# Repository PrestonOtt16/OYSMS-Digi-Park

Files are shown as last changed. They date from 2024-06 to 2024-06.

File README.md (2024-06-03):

# OYSMS-Digi-Park
Preston Ott 6/2/2024
This is a Univerity of Texas at San Antonio Senior Design Project completed on the date of 4/23/2024
Group members: Preston Ott, Josh Swanner, Joshua Moya, Younes Younes, Luis Santillian

The projects goal was too make an app that displays a parking lot map showing which parking spaces are occupied/unoccupied for navigation purposes. 

The projects detailed goal was to create a wireless sensor system that will scan a parking lot.
The scan will be fed to a machine learning model that detects if parking spaces are occupied or not.
The machine learning model will send the parking space data to a server hosting a mobile app.
The mobile app will use the data to create and display a map of the parking lot to the mobile app user.
The mobile app user will use the map too find the nearest unoccupied parking space.

Link to demonstration of final project:
https://www.youtube.com/watch?v=veE5finqBho

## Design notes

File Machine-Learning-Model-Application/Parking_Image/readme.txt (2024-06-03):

This directory holds the image the rpi4 camera captures

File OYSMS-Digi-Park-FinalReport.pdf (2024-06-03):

Final Report – 5/2/2022

EE/CpE 4813 – ECE Capstone Design II

Spring 2023

Instructors: | Johnathan Votion Ph.D, Professor August Allo.
Team name: | OYSMS Digipark
Team members: | Preston Ott, Younes Younes, Joshua Swanner, Joshua Moya, Luis
Santillan
Description: | The Parking Space Indicator is a project that will map a parking lot,
develop a scanner to scan parking spaces and develop an app to display occupied/unoccupied parking spots in the parking lot.

Executive Summary
The OYSMS Digipark team's prototype scanner and app were developed with the goal of providing real-time occupancy status of a parking lot to users. The project was designed to alleviate the stress and frustration of finding a parking spot by allowing users to check the availability of parking spots before they arrive at the parking lot. The team incorporated a machine learning model to accurately detect the occupancy of parking spots, which was transmitted to a receiver and stored in a SQL database for easy retrieval by the app. The team also made adjustments to the hardware components, such as the camera and microcontroller, to ensure the reliability and ease of use of the final product.

Overall, the project was a success, with the final prototype demonstrating the team's ability to create an innovative solution to a common problem. The team's ability to adapt and innovate when faced with challenges was crucial in achieving the project goals.

Here are two images of the final the prototype:

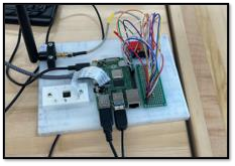
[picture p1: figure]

Image 1. Final Prototype

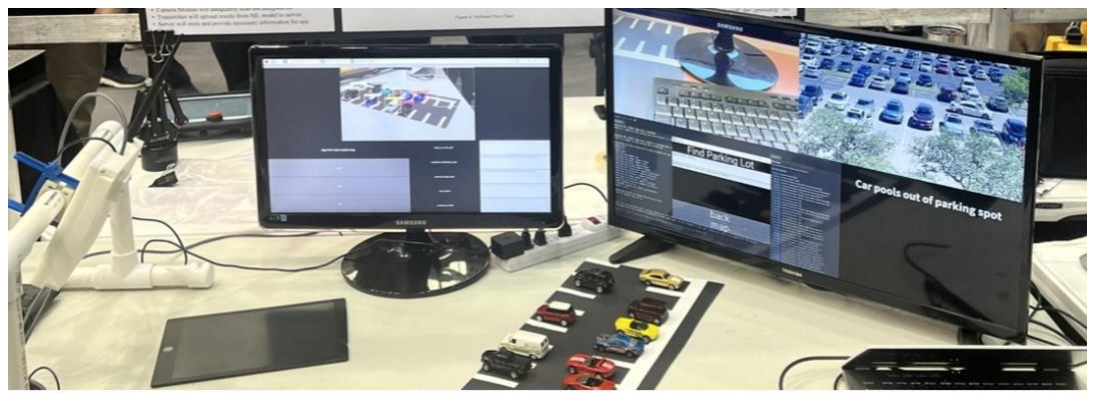
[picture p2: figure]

Image 2. Final Prototype working

Additionally, here is a video demonstration of the final prototype:

Parking Project Demonstration-2023-OYSMS-Digi-Park (https://youtu.be/veE5finqBho)

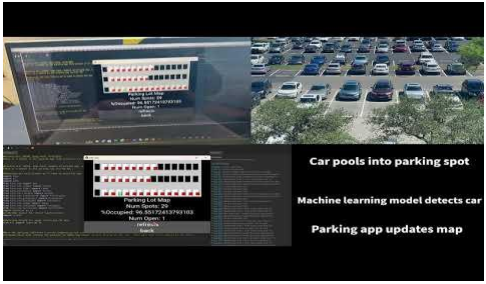
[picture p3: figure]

Video 1: Video of Final Prototype Working

### 1.0 Introduction

We are OYSMS Digipark. This project aims to set up a scanner in a parking lot which can also update an app that can be viewed on an electronic device. The project will first take a picture through the camera of the desired parking lot that the user is looking for. The camera will then send that photo to the machine learning model to process the Afterwards, a spot array will be created that contains 1’s and 0’s depicting the occupancy of each parking spot. The transmitter will then send the spot array to the receiver. Once received the receiver will update a SQL database that will be used to store the spot array. The user will type in the desired address in the app which will request a spot array through the server. Finally, the server sends the spot array to the user and the users app will display the parking spots that are occupied and unoccupied with vehicles.

### 1.1 Project Schedule

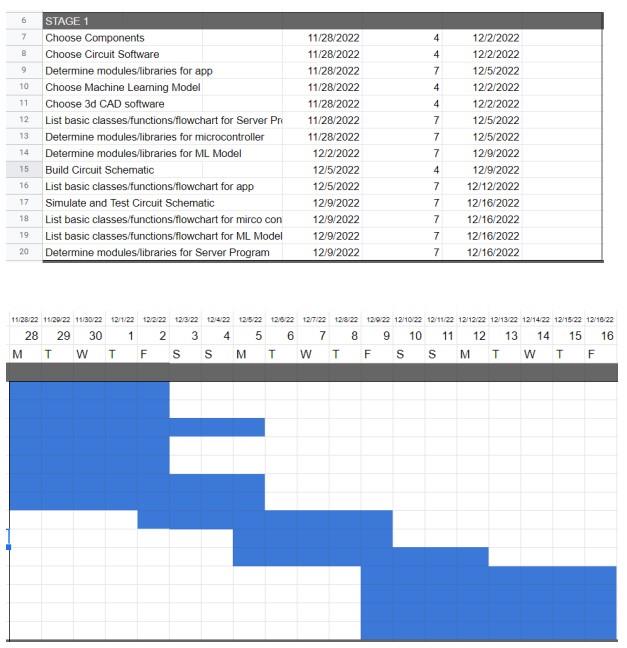
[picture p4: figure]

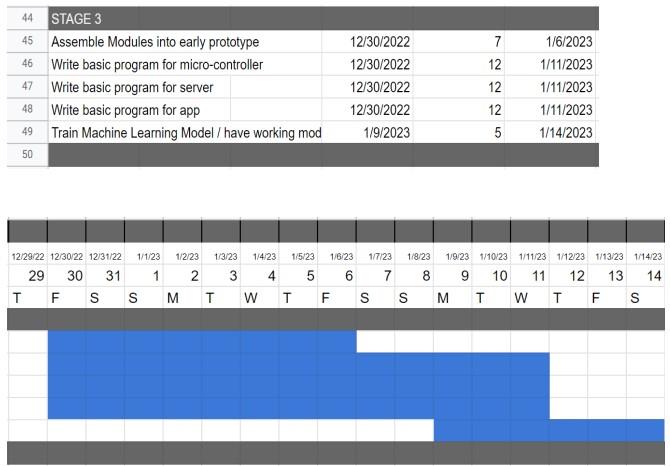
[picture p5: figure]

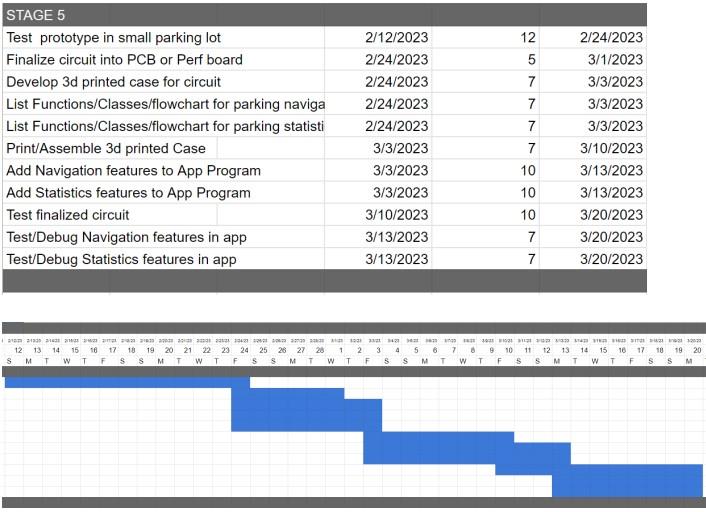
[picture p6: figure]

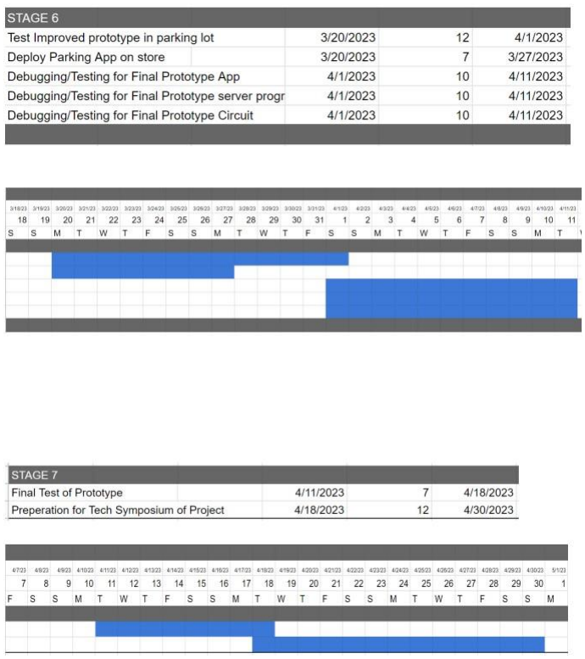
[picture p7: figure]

### 2.0 Need Being Addressed

A problem that has been an issue for some time now is the parking around campus. Finding a parking spot on campus can be tough because there are so many people trying to go to class, and with a limited number of spots it is hard to know if other parking lots have open parking spots. This will help many people find parking on campus with little to no struggles. All businesses and buildings that have parking lots will benefit from this solution because customers avoid shops due to inadequate parking space. All people who use a motor vehicle will benefit from this solution through fuel and time savings.

### 3.0 Literature and Patent Search Results

Researching Parkam’s AI-based deep machine learning software provided the team with a vision of how our product should function. Their patent for a training system for automatically detecting parking space vacancy providing inspiration towards training our own machine learning program. The ability to identify parking spots and their states accurately being the main inspiration. With Cleverciti’s parking sensor providing the basis for the physical aspect of the OYSMS scanner. Although ours is made of a more cost-effective material, uses a single camera and customizable clamps for adjustable attachment to various surfaces.

### 4.0 Marketing Analysis and Market Strategy

The market potential of this product is vast and promising. In a full parking lot,
customers will get frustrated and start to leave the premises, meaning the company will start to lose money. Companies could use this app to help reduce the amount of potential customers from going to a different store. With this product implemented into businesses parking lots, customers would want to come more often because of how convenient it is for them to find a parking space. This would potentially make the business grow and the product grow as well because then customers would start to look for businesses that are associated with the app to start shopping at.

### 5.0 Engineering Design Constraints

The main constraint of the application are the guidelines placed on by the app stores and the capabilities of the programming language being used to develop the app. For the device there are rules and standards given by the FCC when transmitting radio frequencies. Another constraint would be communicating the devices' information to the server running our application.

### 6.0 Product Requirements/Specifications

This section of the document lists specific requirements and specifications for OYSMS DigiPark. Requirements and specifications are divided into the following sections:

1. User requirements and specifications. These are requirements and specifications written from the point of view of end users, usually expressed in narrative form.
2. System requirements and specifications. These are detailed requirements and specifications describing the functions the system must be capable of doing.
3. Interface specifications. These are requirements and specifications about the user interface, which may be expressed as a list, as a narrative, or as images of screen mock-ups.

### 6.1 User Requirements and Specifications

6.1.1 User interface

The user interface will be available from a mobile app that the user will be able to use on their cellular device. They will be able to look at the parking spaces available and the parking lots that are available and the ones that aren’t available.

6.1.2 Ergonomics

This product will be in the air above the reach of anyone, so that it will be able to scan the designated area. This will make sure it is not in anyone’s way.

6.1.3 Training or skills required

Technical understanding and experience of operating a smart device is required for the app. To be able to use the app you just must know how to use your phone. Being able to navigate through the app without any trouble. You also need to be able to drive and/or have navigation skills to get to the designated spot.

### 6.2 System Requirements and Specifications

6.2.1 Physical Characteristics

- Raspberry pi 4
- Weight: | 46 g
- Dimensions: | 85.6mm x 56.5mm
- Transmitter
- Weight: | 15.4 g
- Dimensions: | 0.63x0.63x0.07 in
- Camera
- Weight: | 34 x 24 mm
- Dimensions: | 20 g

6.2.2 Material Requirements

- 3-D Printed case

6.2.3 Electrical Requirements

- Raspberry pi 4:
- Power: 5V DC, 2.5A
- Operating System: Python
- Operating Temperature: 0-50 degrees C

6.2.4 Abilities

- Take an image and processing that image

6.2.5 Limitations

- Not enough range to cover every parking lot simultaneously
- Wi-Fi signal not strong enough

6.2.6 Equipment or materials required to use the product

- Smart Phone
- Mobile App installed

6.2.7 Equipment interface requirements

- SD memory storage reading capabilities

6.2.8 Handling and storage requirements

- Needs to be up high in the air

6.2.9 Cleaning and Sterilization

- Cleaning the camera is going to be essential for us to get a clear picture of the parking lot

6.2.10 Product maintenance and serviceability

- Cleaning the camera to get a clearer picture
- Fixing the bugs of the app as we go along
- Wi-Fi needs to be available

6.2.11 Operating parameters

- OV5647
- Power Supply: 3.3V - 5V
- Pixel Size: 1.4µm x 1.4µm
- Temperature: -10°C～+55°C
- Raspberry pi 4
- Power Supply: 5V DC, 2.5A
- Temperature: 0-50 degrees C
- RFM95
- Power Supply: 3.3V
- Temperature: -55°C～+115°C

6.2.12 Repeatability and reproducibility

- The project is going to be able to refresh and be able to repeat each process every 15 seconds. If the camera is going to be clean, then there should be no problems.

6.2.13 Reliability

- Depending on the weather conditions and other conditions, this product will be reliable on any day. Up to the user to refresh the app to see availability.

6.2.14 Mechanical safety features

- 3-D printed case

6.2.15 Electrical safety features

- Raspberry Pi 4
- Wires
- Transmitter
- Camera
- PCB

### 6.3 Interface Requirements and Specifications

Access and translation between the digital camera and transmitter should be monitored by our microcontroller. For the sake of consistent image upload to a database server which will translate said information into a readable form for our users. From this, our users will interact with the given parking information via an application that will take user input and guide them to their desired location. The device will be detached from the elevated location for maintenance if physical repairs are necessary and updates to the server can be done at a separate location.

### 7.0 Engineering Codes and Standards

Below are the IEEE standards for transmitting data over radio frequencies and other wireless forms of communication. As our devices require wireless connectivity to communicate with the server and application, these standards and regulations are required:

IEEE Standard for Radio-Frequency Energy and Current-Flow Symbols: Symbols to inform people about the presence of potentially hazardous levels of radiofrequency energy or the presence of contact current hazards in the frequency range of 3 kHz to 300 GHz are specified in this standard. Guidance is given about how these symbols should be used on warning signs and labels.

IEEE Recommended Practice for Radio Frequency Safety Programs, 3 kHz to 300 GHz: Elements of a radio frequency (RF) exposure safety program that provide reasonable and adequate guidance for preventing exposures in excess of recognized limits to electromagnetic fields from RF sources that operate in the frequency range of 3 kHz to 300 GHz are described in IEEE Std C95.7™-2014. The means for accomplishing this are classifying exposure locations into one of four categories based on the potential hazard, as defined by exposure limits, and specifying appropriate controls for each category. Such controls include engineering and administrative controls as well as the use of personal protective equipment, placement of appropriate RF safety signage, designation of restricted access areas, the use of personal RF monitors, and RF safety awareness training. These recommendations are not intended to apply to the purposeful exposure of patients by or under the direction of medical practitioners but can be used in the development of safety programs for medical staff and other persons working with or incidentally exposed to RF fields, and for those wearing implanted or external medical electronic devices. Although designed to complement IEEE Std C95.1™, this recommended practice may also be used for the development of programs to ensure conformance with other guidelines, standards, or regulations for controlling human exposure to electromagnetic energy.

IEEE Guide for EMF Exposure Assessment of Internet of Things (IoT) Technologies and Devices: In the wireless communication field, 5G and Internet of Things (IoT) solutions are the main emerging technologies and future wireless communication will rely on them. A methodology for classifying IoT devices based on radio frequency (RF) exposure characteristics is provided. Classification is based on frequency, bandwidth, radiated power, and typical installation configuration. Links between device class and available measurement/computational standards are provided.

### 8.0 Design Concepts

When discussing how the go about this project our team settled on three concepts to compare and discuss. Below is a Pugh Matrix with weighting of importance displayed within the second column alongside the determining criteria. From which the scanner module design was selected with a total score of 785.

Criteria | Weight | Drone | Sensor | Scanner Module
Cost: | 20 | 5 | 4 | 8
Efficiency: | 30 | 6 | 8 | 8
Information Quality: | 10 | 8 | 10 | 8
Transmit speed: | 10 | 8 | 8 | 8
Temperature ratings: | 15 | 9 | 8 | 8
Scan Rate: | 15 | 6 | 8 | 7
Score = | 100 | 539 | 740 | 785

### 8.1 Drone Concept

A concept utilizing a drone to periodically survey an area and collect parking lot information. However, as power constraints are quite limiting, scan rates are not as frequent as desired and less efficiency in larger areas, this idea was inevitably the least favored amongst the three options.

### 8.2 Sensor Concept

The light sensor method would utilize a scanner device that would project a signal upon a sensor on the ground in a parking spot. The sensor would receive and reflect the signal back unless something such as a vehicle blocks the signal, which would notify the main device that the spot is occupied. While this method is effective for condensed areas, it’s not as effective in larger lots where several receiver nodes would be required. Also, the signal could be blocked by something not actually occupying the space such as a person blocking the sensor.

### 8.3 Scanner Module Concept

Using a scanner module and a machine learning algorithm, this device could observe a lot and detect changes within real time like the sensor concept. Trading some detection speed and a bit of information quality for more accuracy and cost efficiency in larger areas, the scanner module is the more desirable option by comparison. This device could even identify the difference between a vehicle and a person or tree branch that’s simply obstructing view with more advanced Artificial Intelligence.

### 9.0 High Level Block Diagram

The parking lot scanner block consists of a scanner, a control system, a transmitter, and a power supply. Firstly, the power supply subsystem will provide voltage to the other subsystems in the parking lot scanner. Between 3.3 and 5 volts of power will be input to the power supply, note that many circuits operate. The first major subsystem is the scanner. The scanner will be given an input of a physical car and/or parking spot. The scanner may be given an individual car/parking spot, or it may be given several cars/parking spots dependent on the type of scanner being used (ultrasonic, photodiode, camera, etc.). The control system will act as a brain for the whole parking lot scanner. The main purpose of the control system will be to take the data from the scanner and interpret it. It may then simplify the data and output the data to the transmitter along with instructions. The instructions sent to the transmitter may consist of how often to transmit, what data to transmit, what frequency to transmit at, when to turn off, etc. The main input of the transmitter will be the data of the scanner (from the control system) and will output the same data over the air. The main purpose of the transmitter is to communicate and update the server with the important information sent from the control system. The parking space app will be decomposed into 2 main parts: the client app and the server program. We’ll require a server for our project which can be any desktop computer. The server will take in 2 types of data, and these are client requests and scanner data. The second part of the parking space app will be the client app. This app will run on the client's device, which will most likely be a smartphone.

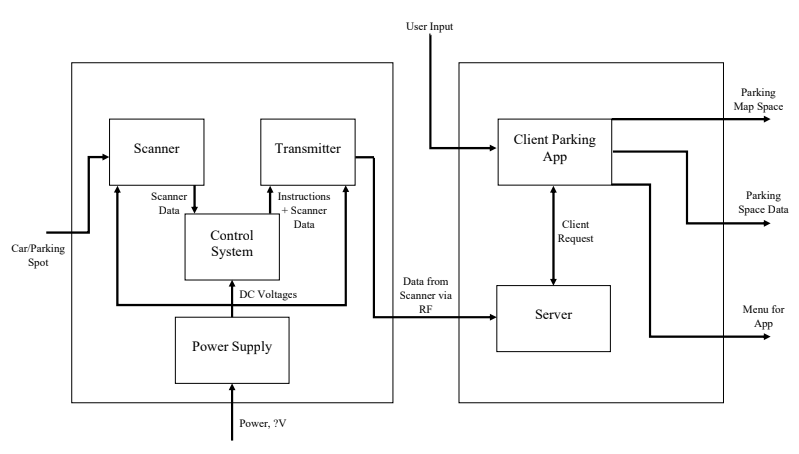
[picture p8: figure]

Figure 1: High Level Block Diagram

### 10.0 Major (Critical) Components

### 10.1 Camera Module

Criteria | Weight | OV5647 OmniVision
MT9P11
ONSemi

S5K4ECGX
Samsung
Cost: | 15 | 7 | 5 | 8
Output Formats: | 17 | 9 | 6 | 7
Image Quality: | 30 | 10 | 10 | 10
Interfacing Capabilities: | 19 | 9 | 7 | 7
Temperature ratings: | 10 | 8 | 9 | 8
Pixel Size: | 9 | 9 | 9 | 9
Score = | 100 | 989 | 781 | 833

Functional requirements for the digital camera Pugh matrix are cost, output formatting options, image quality, interfacing capabilities, temperature ratings, and size of pixels. The three digital cameras being analyzed are the OV5647, MT9P11, and the S5K4ECGX. The cost was weighed as the middle of the pack (15) because most camera modules have around the same price for similar specifications. Output formatting was rated similarly (17) because of how common the most important format options such as RAW, YCbCr422, and JPEG are across various models. Image quality is a crucial factor in determining our device (30) as the clearer the images provided, the smoother our program can operate.

Temperature and pixel size are the least consequential factors (10 and 9 respectively) because after observing various models most are more than capable of operating in extreme temperatures. With pixel size in a comparable situation as most camera modules have a 1.4um x 1.4um pixel ratio amongst the similar specifications. The OV5647, MT9P11, and the
S5K4ECGX got scores of 989, 781, and 833, respectively. Taking all the functional requirements into account the OV5647 surpasses the others in terms of quality.

### 10.2 Control system

Criteria | Weight | OV5647 OmniVision
MT9P11
ONSemi

S5K4ECGX
Samsung
Cost: | 10 | 8 | 9 | 10
I/O Ports: | 20 | 10 | 7 | 5
Programmability: | 20 | 10 | 6 | 8
Wi-fi Capabilities: | 10 | 9 | 7 | 10
Processor Speed: | 20 | 10 | 7 | 9
Storage: | 20 | 7 | 9 | 10
Score = | 100 | 910 | 740 | 840

Functional requirements for the microcontrollers Pugh matrix are cost, I/O ports, programmability, Wi-Fi capabilities, processor speed, and storage. The three microcontrollers that were being analyzed are the Arduino uno rev3, raspberry pi4, and the esp32. The cost weighed about 10 percent of the total with all of the microcontrollers ranging from a certain range, but with some slightly cheaper than the others. The I/O ports were rated at (20) because each microcontroller had either only 2 or 3 I/O ports while others had 5 or more. The Programmability was also weighed the same because some microcontrollers can only be programmed in one language while others can be programmed using more than one.

The Wi-Fi capabilities were weighed at (10) because it is a feature that is useful without having to use an ethernet cable. The Processor speed is the same weight of (20) and we need this to be able to make sure that the microcontroller can process what we send to it fast enough to keep up with what we are doing. Storage is also a big part of the weight with (20) having a lot of storage is good so that we can store the program code. With all these functional requirements, we can see that the Raspberry pi4 is the best option with a score of 910, the ESP32 is the second-best option with a score of 840 and then the Arduino uno rev3 is the last option with a score of 740.

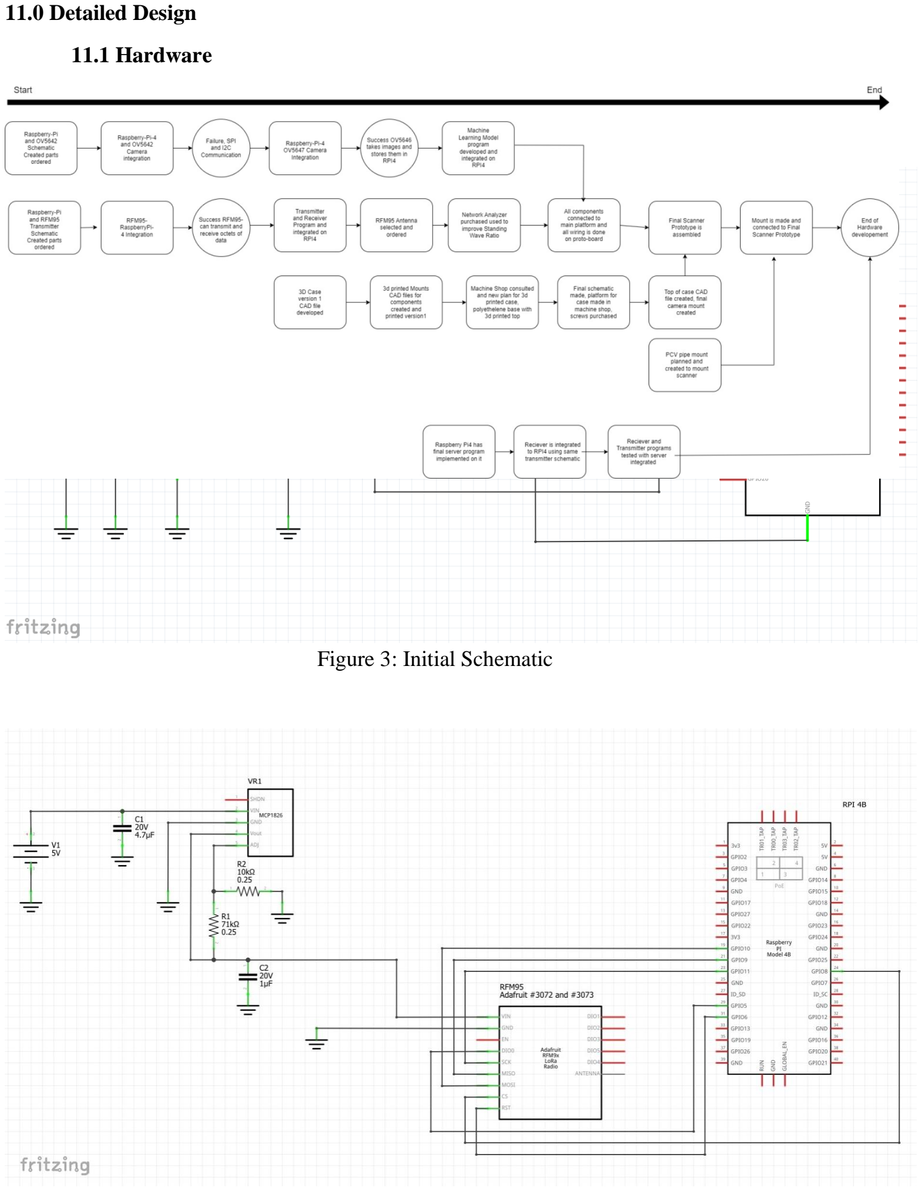
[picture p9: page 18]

### 11.0 Detailed Design

### 11.1 Hardware

Figure 2: Detailed Hardware Breakdown

Figure 3: Initial Schematic

Figure 4: 2

nd version of schematic without camera

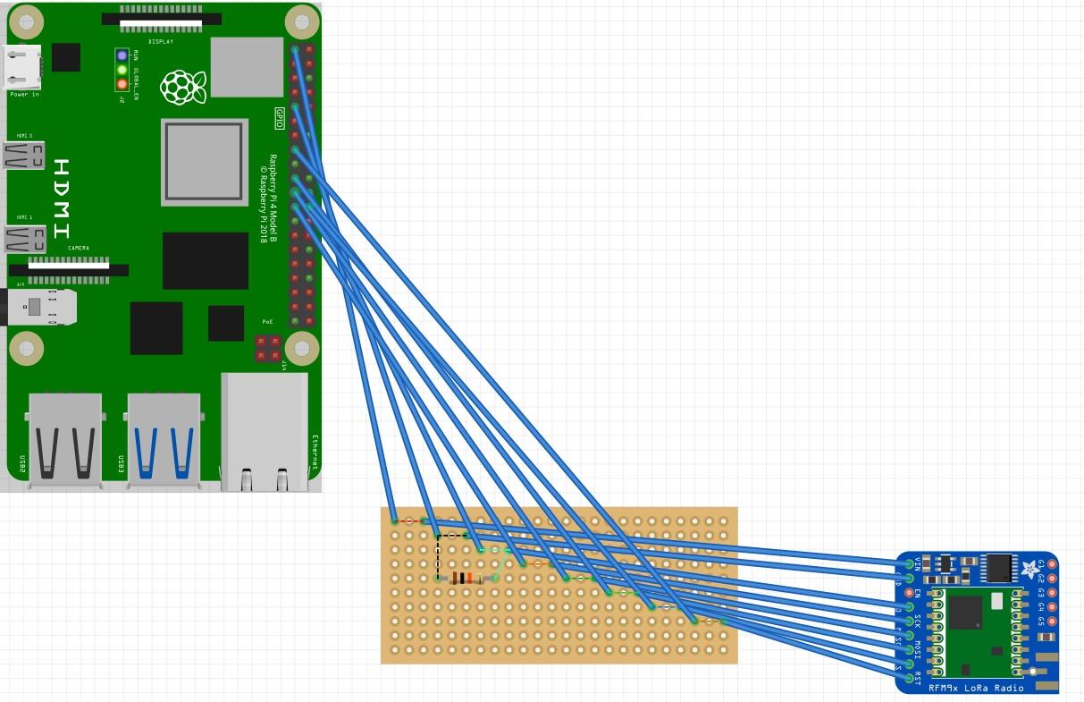
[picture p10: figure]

Figure 5: Final Schematic without camera

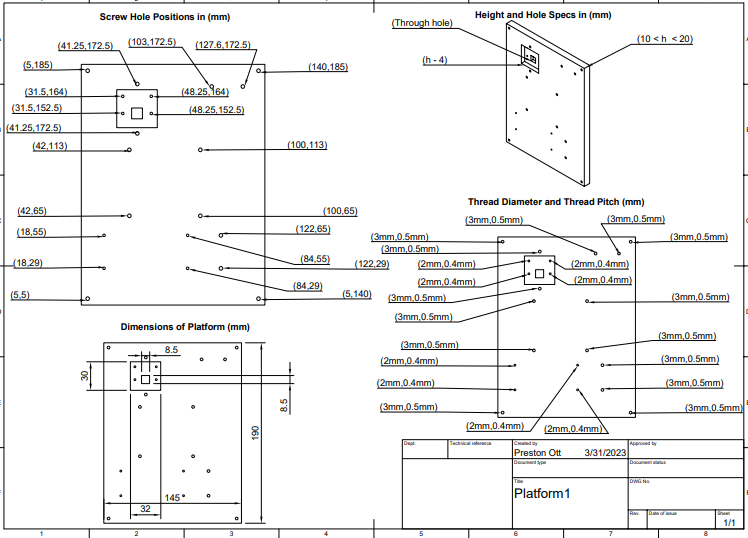
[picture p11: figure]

Figure 6: Plan for enclosure

The hardware ideas were split up between the majors. The computer engineers were to determine the best microcontroller to be used for the purpose of the project. While the electrical engineers were to focus on the transmitter/receiver, power supply, and the scanner.

### 11.1.1 Power

As seen in Figure 2, the raspberry pi was initially going to be powered with a voltage regulator. We then switched which regulator to be used after checking the power requirements for the raspberry pi as seen in figure 3. The resistors and capacitors were added to configure the regulator for the raspberry pi based of the data sheet. As time progressed, we saw more use with using the regular power supply made by a company and get rid of the regulator all together.

### 11.1.2 Scanner

The first iteration of the project used a different scanner (camera) than the final version. The scanner chosen ended up being a camera due to the capability of scanning multiple parking spots, which would otherwise be challenging with other sensors, such as ultrasonic. Early in the process the OV5647 was chosen to be the scanner, but due to difficulty interfacing with the raspberry pi, we decided to switch to the OV5642. Which was one of the first cameras produced to interface directly with the raspberry pi. This made the process of taking images much simpler, while still being an efficient camera for the project.

### 11.1.3 Transmitter/Receiver

The transceiver chosen held from beginning to end as seen in the schematics. The RFM95W was chosen to serve as the transmitter and receiver. One of the team members has had previous experience with the module at a past internship and has held this module with high regard. The transceiver chosen needed to be able to have a wide range to adapt to different parking lots, it also had to be able to send at least 80 parking spots worth of data. The RFM95, which has LoRa modulation scheme, has both long range while being able to send up to 255 bytes (or in this case parking spots) of data making it a good fit for Digipark.

### 11.1.4 Enclosure

Although not included in the hardware block diagram, the device needs to have an enclosure to secure and stabilize all of the parts. The process to design the case was to make a form factor efficient in size so that it could fit all the parts while being as small possible. The material to be used for printing was a resistant material to weather conditions while not conducting electricity. The material chosen that fit these requirements was ABS.

### 11.2 Software

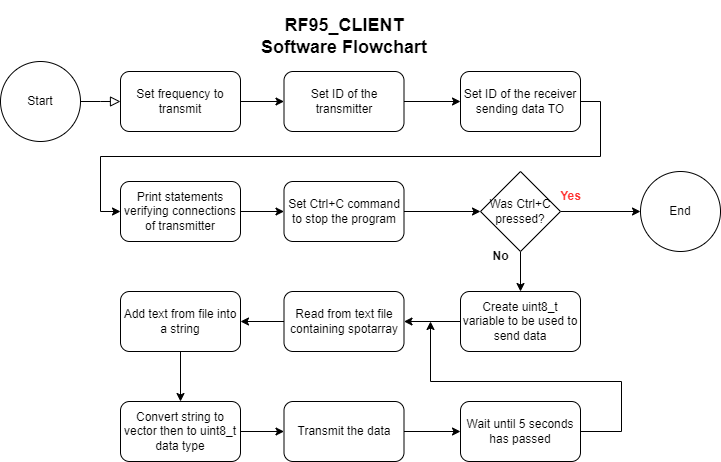
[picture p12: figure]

Figure 7: Transmitter Flow Chart

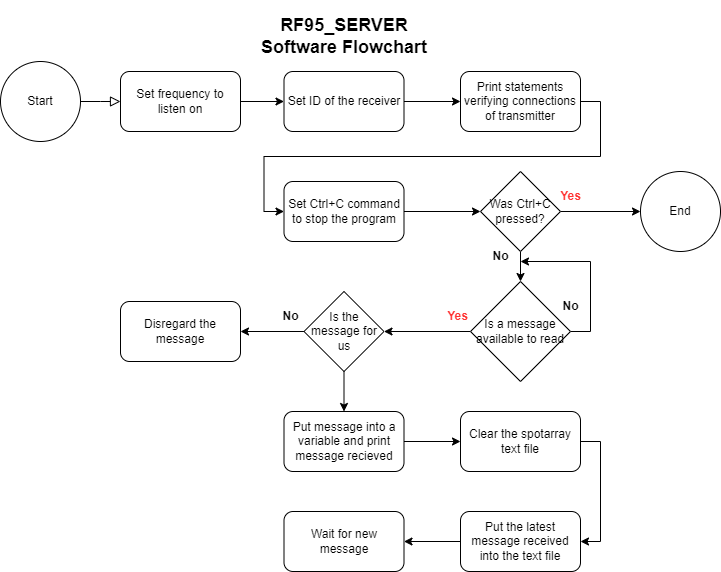
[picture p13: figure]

Figure 8: Sever Software Flowchart

The division of the software development is relatively straight forward. Having a member work on the code for whichever component they are most familiar with. While those with more advanced coding experience wrote code for the server and app.

### 11.2.1 Transmitter Software

The software starts by initializing the module itself, there is a required set of information for the first 8 bytes of every LoRa message, which contains information such as the name of the transmitter and where to send the data to. The program is setup to type Ctrl+C in the Linux terminal to end the program, but otherwise continue the program forever, since the device would always scan for parking spots. The Ctrl+C command would be used during less busy hours of a parking lot to save power. The way the module work, the data needs to be formatted into an array of the uint8_t data type, each array spot would contain 1 byte of information. The data being transmitted is the spot array which comes from a text file, which the transmitter program has to read. After reading the text file, a few data type conversions occur since there is no direct conversion from a text file to a uint8_t data type. After the conversions are complete, the transmitter finally sends the data to the receiver, and continually does this every 5 seconds.

### 11.2.2 Receiver Software

The receiver software starts by initializing the module, similar to the transmitter. The difference is that the ID will be used in a function that detects if the LoRa message was for the specific receiver. A similar loop of using Ctrl+C to end the program is used in the receiver as well, except the receiver always listens for a message. Once a message is received, the code checks if the message was for the receiver and discards the message if not. If the message is for the receiver, a second function is called to read the message and store the data in a variable. Afterwards, the program puts the message into a text file to be read and be manipulated by the server and database and continues to listen for a new message.

### 11.2.3 App Software

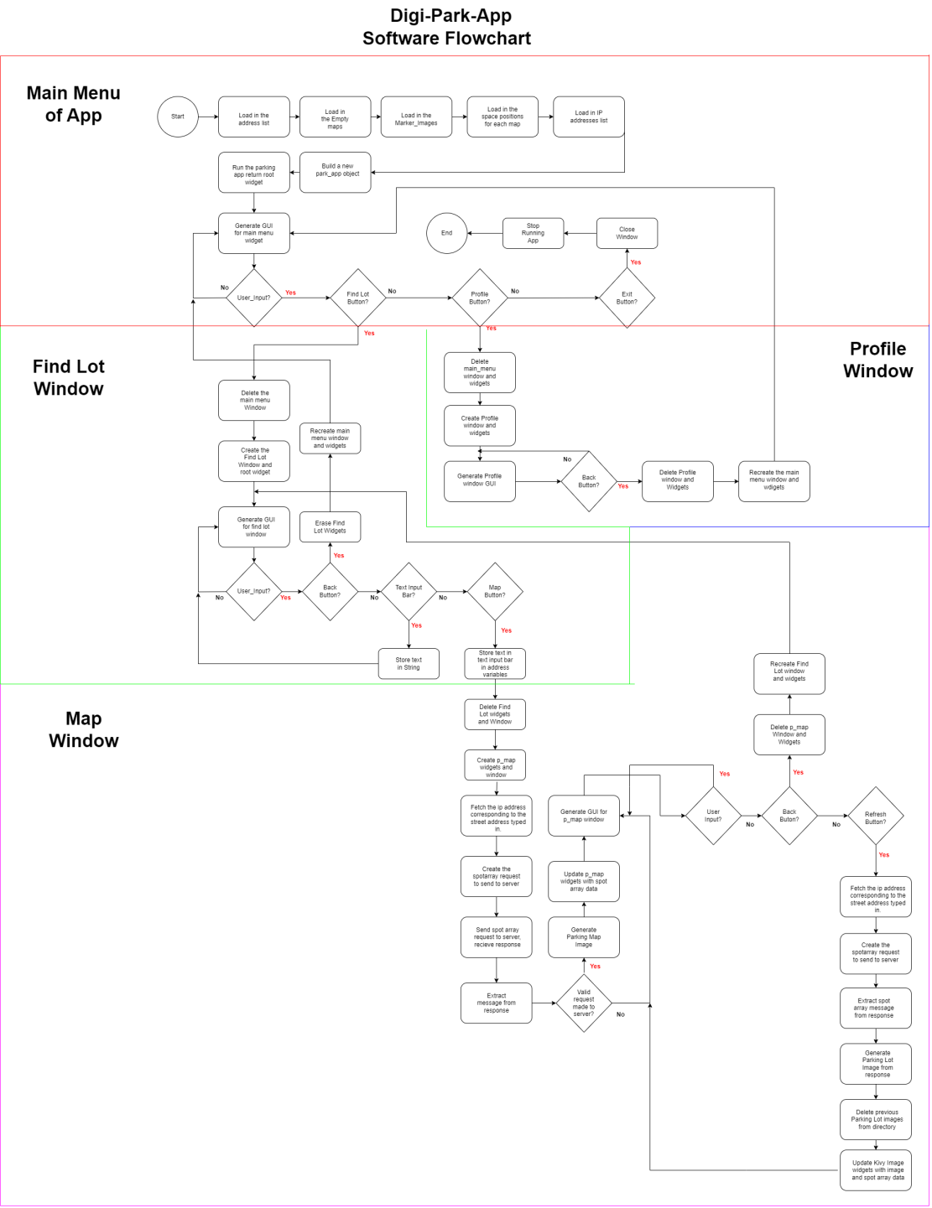
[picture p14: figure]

Figure 9: App Software Flowchart

The app software starts by loading in all the content Empty maps, position of parking spots, ip addresses, street addresses of parking lots, that it will need to properly function. Then an app object is created to generate the main menu window. From the main menu the user can navigate to profile window, find lot window. The profile window is not yet created and just contains some text and a back button. The Find lot window allows users to search through the street addresses and search for their own street address. Once a street address is typed into the text input the user can select the map button to receive the current parking lot map for the street address typed in. The app will send a request to the appropriate server for the (spot array) for that parking lot. The app will receive a (TCP) response from the server containing the spot array and close the (TCP) connection. The appropriate map from the Empty map folder will be selected and the parking lot map image will be drawn. Then statistics on the parking lot will be generated from the (spot array) received. The map window will then be drawn with the map image displayed to the user and the parking lot statistics. The user can then choose to refresh the page with the refresh button which will send another (spot array) request to the server to update the parking map image and statistics again. The user can also go back to the find lot window by clicking the back button. The user can navigate back to the exit button and click it, once clicked the window for the app will be closed and the app will stop running. The Kivy library documentation was used to develop the main Kivy app reference.

### 11.2.4 Machine Learning and Camera Software

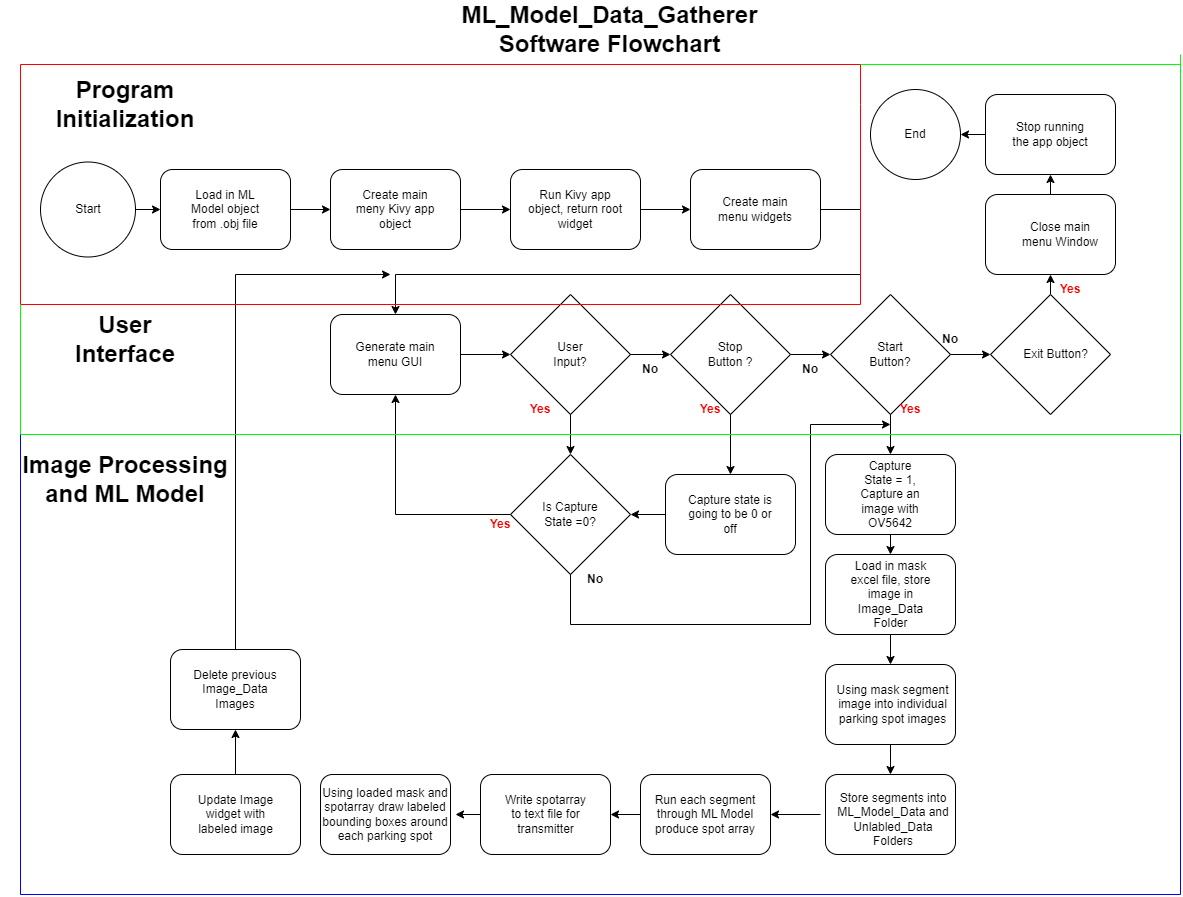
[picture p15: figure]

Figure 10: ML Software Flowchart

The Machine Learning Model and Camera and Software is within a program called ML_Model_Data_Gatherer.py. The program basically goes through the process of scanning and analyzing the parking lot. The program starts by loading a sci-kit-learn MLP Machine Learning Model object into the program. Then it creates a kivy app object and runs it. The app object creates the user interface menu for the user. The user can type in the path to the mask that defines the bounding boxes for the parking lot image. The user can press the stop button to stop scanning the parking lot, the user can press exit to close the kivy window and stop running the application. The start button in the user interface will first take an image of the parking lot and store it. Then it will use the mask to extract images of each individual parking spot. Each parking spot image will be fed through the sci-kit-learn Mahine Learning Model where it will predict if image contains a car (1) or doesn't contain a car (0). Each 1 and 0 is concatenated together to form the spot array for the parking lot. The spot array is then written to a text file spotarray.txt where the transmitter program can read it. Then using the spot array, we generate an image of the parking lot with a bounding box drawn. Then feed the image to the kivy image object to display the image. Then we delete the previous images of the parking lot that are taken and continue to take and process images until user clicks the stop button or exits the application. All code for the Machine Learning Model was made with reference to the sci-kit-learn documentation reference 9 and book Hands on Machine Learning with scikit-learn, Keras, and TensorFlow reference 13 . All code for the OV5642 camera was developed using the lib-camera documentation reference 10.

### 11.2.5 Parking App Server Software

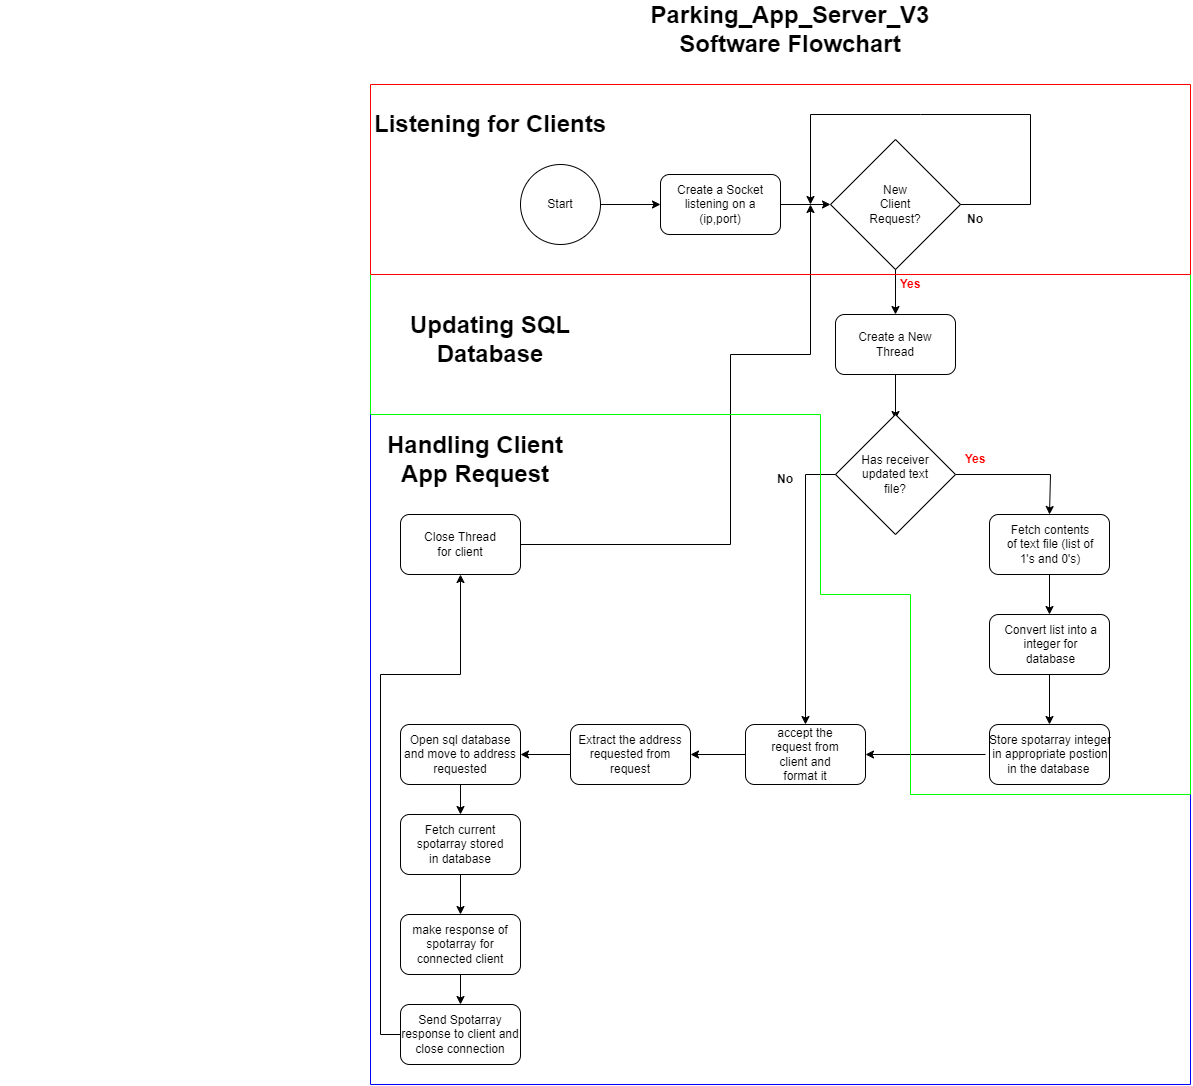
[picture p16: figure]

The parking app software is within a program called Parking_App_Server_V3.py. The server, which is a Raspberry PI 4, is integrated with the receiver and receives the spot array from the transmitter and updates a SQL database. It also handles processing the requests from clients using our parking app. The Server starts by creating a TCP socket and listening for any TCP connections from clients. Once a new client connection is made, we make a new thread to handle them in, we check if the spotarray.txt text file holds new spotarray data. If it has changed then we update the database with the new spot array for the parking lot street address. Then we accept the request from the client connected and extract the street address of the parking lot requested. We navigate through the SQL database to find the latest spot array for the street address. We format the spot array into a response to send to the client. We send the response to the client and close the TCP connection and end the thread. Then we return to listening for more clients TCP connections. The client and server functions of our project were made with reference to the book Learning Python Network Programming, reference 14.

### 11.3 Engineering Analysis and Calculations

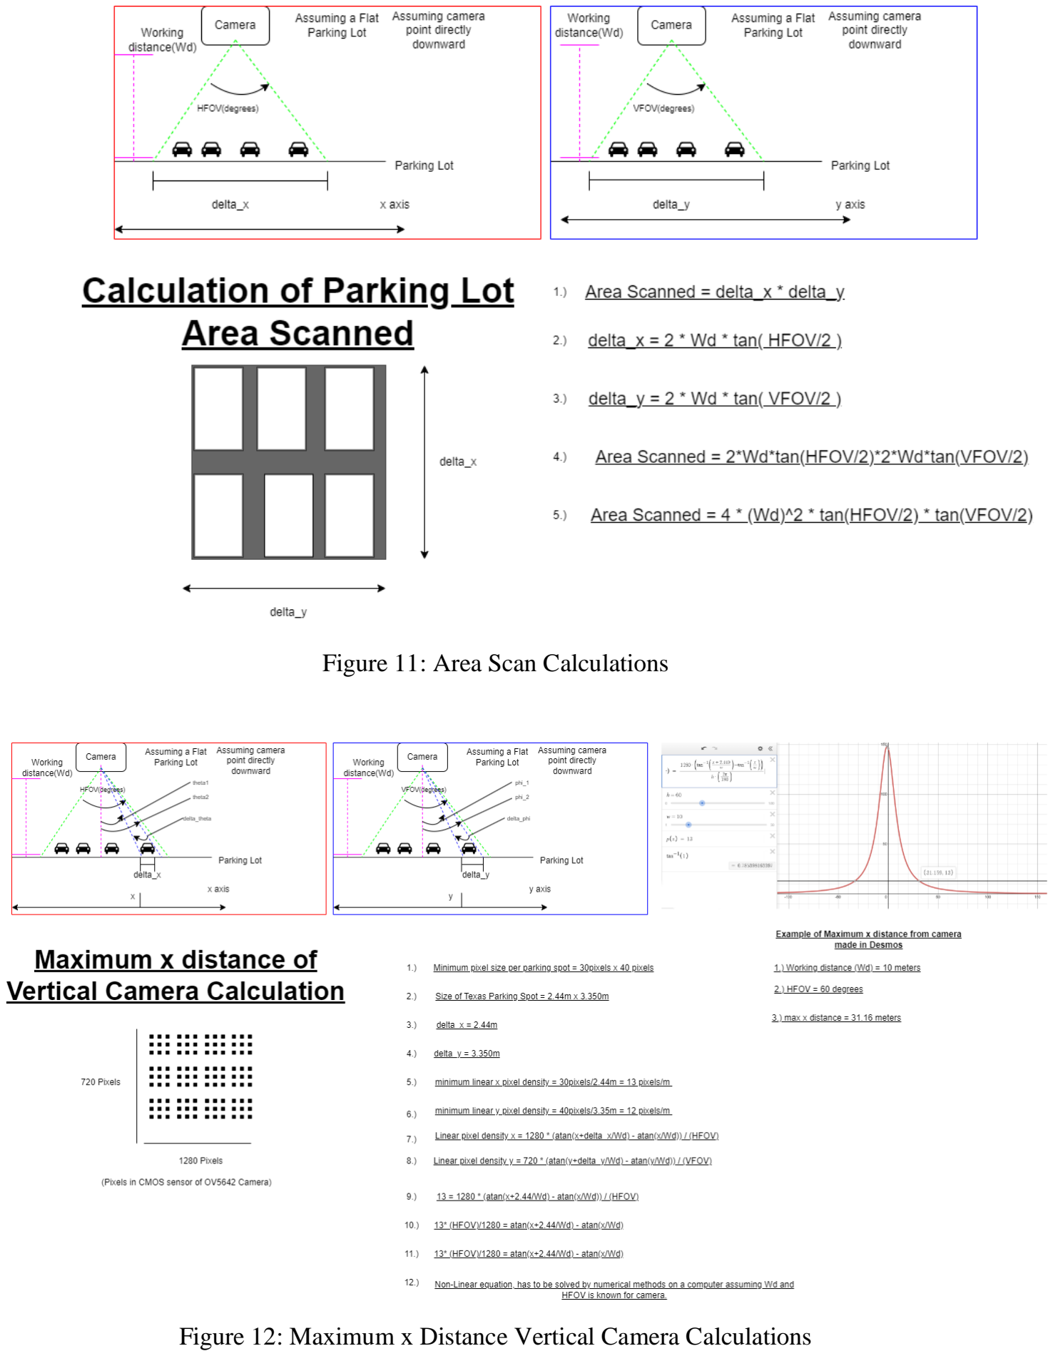
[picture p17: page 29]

Figure 11: Area Scan Calculations

Figure 12: Maximum x Distance Vertical Camera Calculations

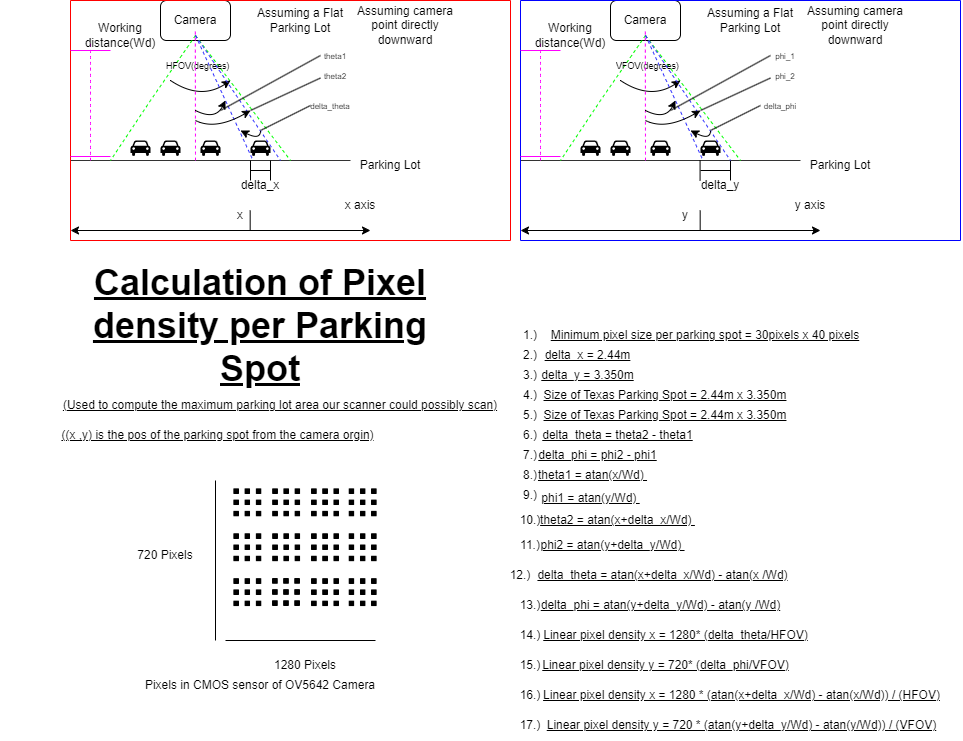
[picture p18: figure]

Figure 13: Pixel Density Calculations

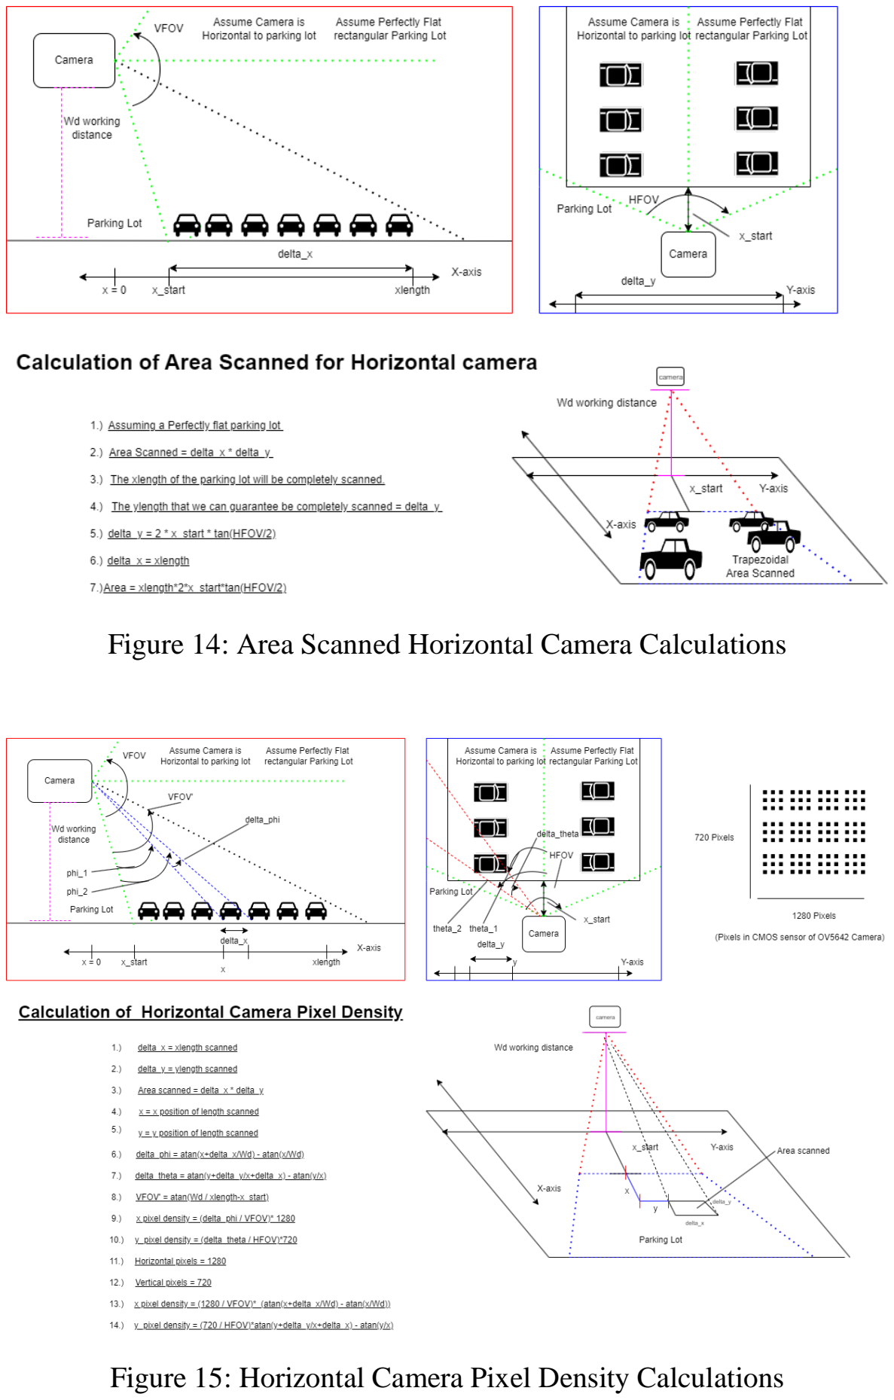
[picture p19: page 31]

Figure 14: Area Scanned Horizontal Camera Calculations

Figure 15: Horizontal Camera Pixel Density Calculations

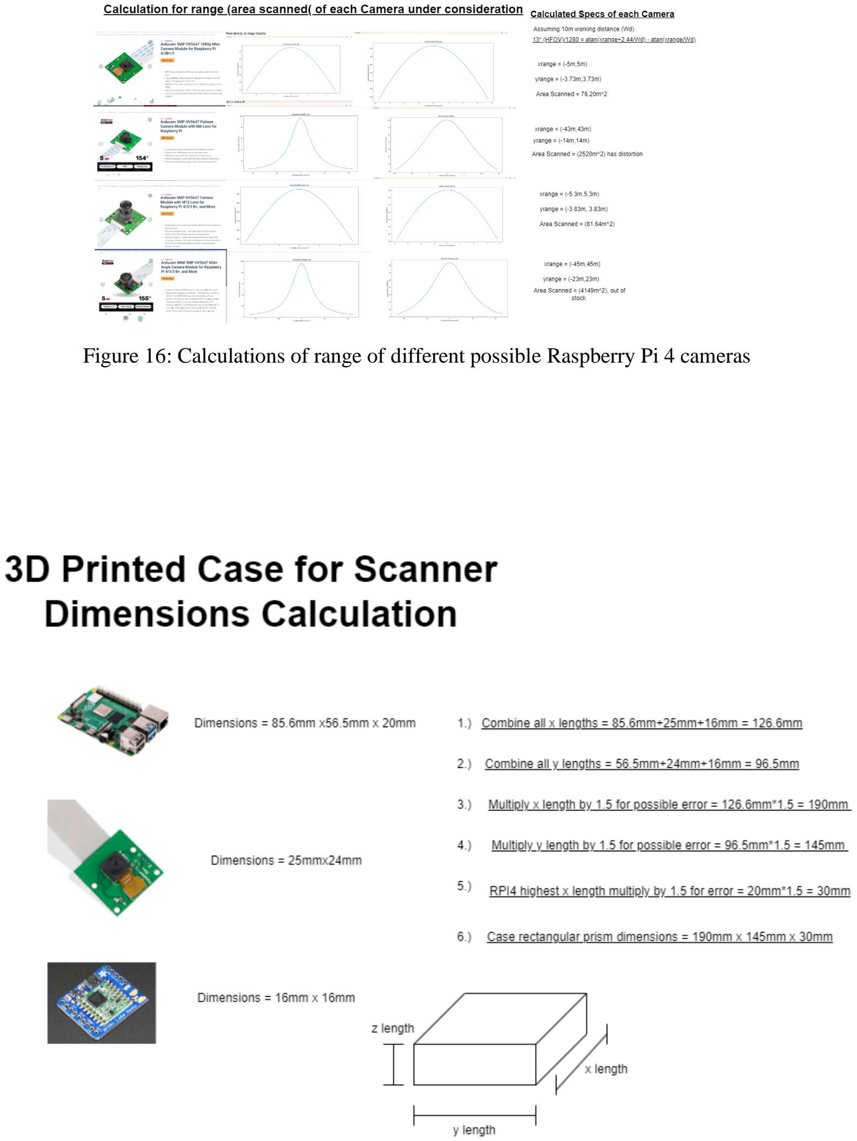
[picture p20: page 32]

Figure 16: Calculations of range of different possible Raspberry Pi 4 cameras

Figure 1: #D Case Dimensions

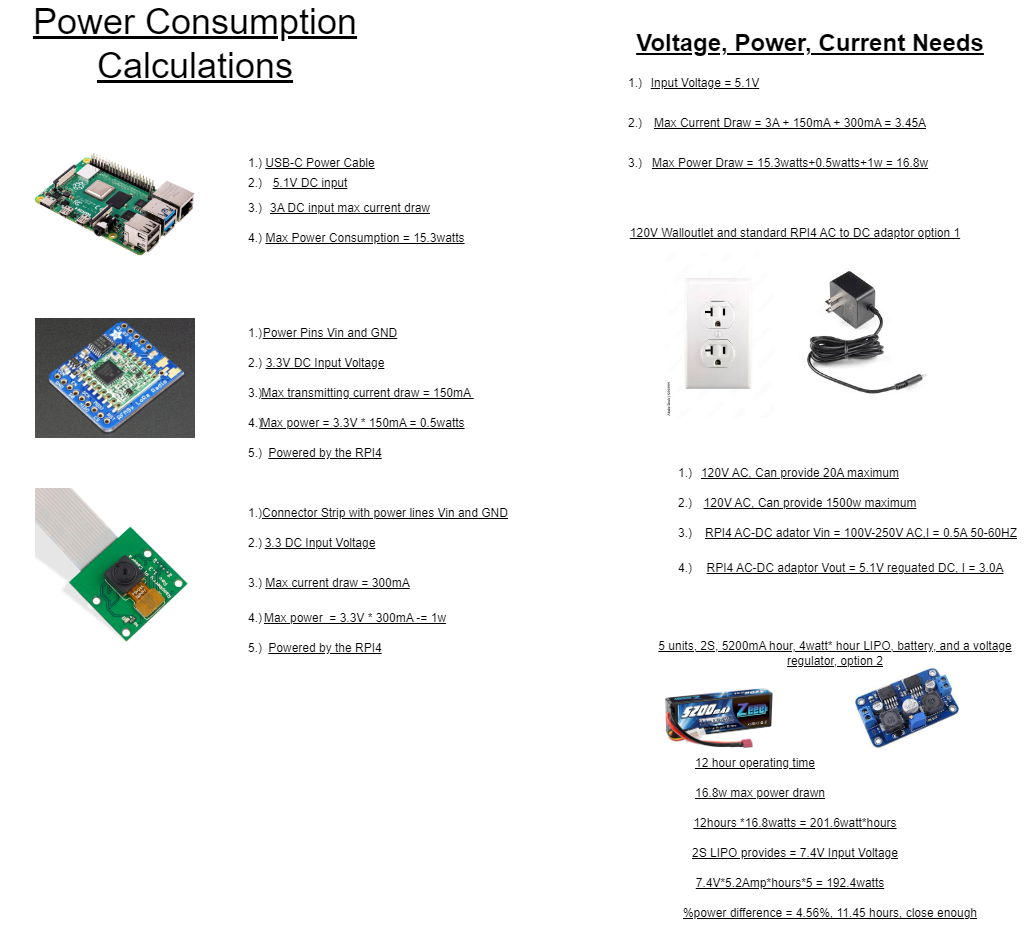
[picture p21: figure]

Figure 1: Power Consumption Calculations

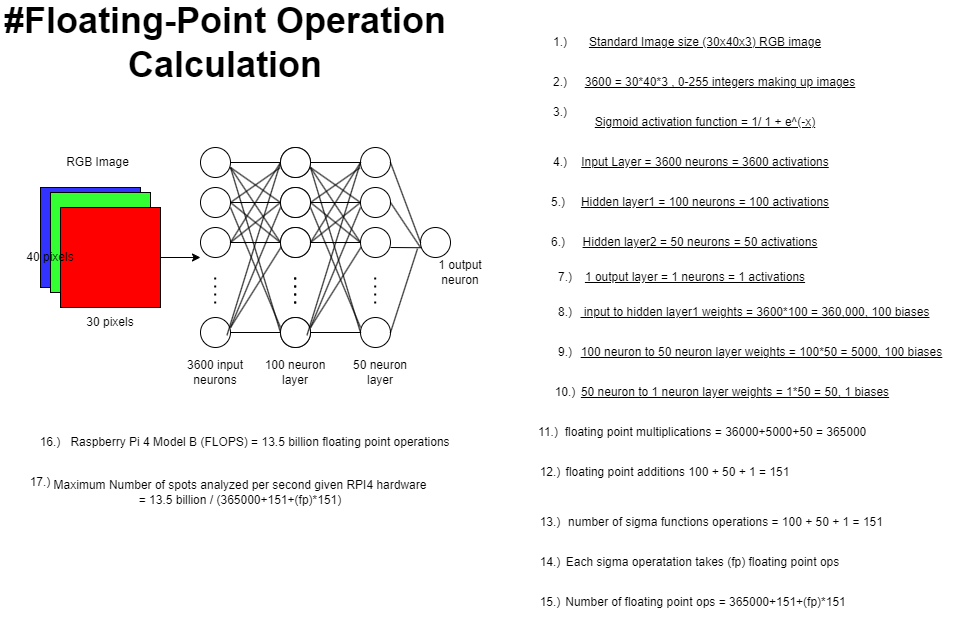
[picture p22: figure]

Figure 19: Machine Learning Model Floating Point Operations Calculations

There are 9 Engineering Analysis Diagrams. 6 diagrams analyze the area and pixel density of the scanner. The other 3 are calculations for power consumption and requirements of our scanner module, 3d printed enclosure dimensions, and the Machine Learning Model number of floating-point operations. The area and pixel density of the scanner calculations were made with reference to the document by Jax Zhang reference 7. Figure 11 shows the calculations of area scanned for a vertically oriented camera (camera point straight down at parking lot from above). Figure 12 shows the calculations for the maximum distance we can scan up to and have sufficient pixel density for our Machine Learning Model to work. Figure 13 shows the pixel density calculations for standard Texas parking space a position (x,y) away from the vertical camera. Figure 14 shows the calculations needed to compute the area scanned of a horizontally oriented camera (camera pointed along the parking lot). Figure 15 shows the calculations needed to compute the pixel density of a patch of area in the parking lot a distance (x,y) away from the camera and a patch size of (x_delta * y_delta). Figure 16 shows a set of different Raspberry Pi 4 camera and the range of the scan they can provide. Given a 10meter working distance and a vertcially oriented camera. Figures 11-16 are important in knowing how many spaces you can scan with a single module and determining how many modules you may need to fully scan a parking lot. Figure.
Figure 17 shows how the dimensions of the 3d printed enclosure were estimated based on the size of each component making up the scanner module. Figure 18 shows how the power consumption, voltage and current draw of the scanner module were estimated by looking at each components required voltage, max current draw, max power draw. 2 options for powering the scanner are proposed, a mobile LIPO battery, or a wall outlet with an AC-DC voltage regulator.

Figure 19 estimates the number of floating-point operations our Machine Learning Model will need to perform in order to make a (occupied) (unoccupied) prediction on an image of a parking space. This is important because it defines the limitations of our hardware and gives us an estimate of how many seconds, we’ll need to fully scan a parking lot with parking spaces.

### 12.0 Major Problems

### 12.1 Error Code with Transmitter and Server

An issue would occur occasionally between the server and transmitter where the encoding of the transmitter wasn’t UTF-8 and therefore couldn’t be properly put into a text file. The purpose of the text file was to communicate between the different programs because the transmitter/receiver was written in C++ and the other programs were written in Python. The server would read from the text file, and if the text file didn’t have UTF encoding then the server would run an error and stop the program completely. The work around was to run the program again, because the error wouldn’t occur frequently, another solution would be to solder the antenna on with better connections.

### 12.2 Obtaining a Testing Location and Footage

Procuring a location to test our prototype would become a reoccurring issue, with the UTSA campus not wanting anything attached to light fixtures. After consulting our instructor, a compromise we came to with the campus was to build a temporary stand and set up the scanner inside one of the buildings next to a lot, looking outwards towards the lot from a window, if a class isn't in session during recording.

### 12.3 Machine Learning Model %accuracy and computational expense

The final Machine Learning Model trained had high accuracy on occupied parking lots with a high % of spots occupied. The Machine Learning model had lower accuracy on parking lots with high% of spots unoccupied. This major problem most likely comes down to the low parameter count for Machine Learning model and the dataset used only containing images from 3 parking lots over the course of a year. The Raspberry PI 4 hardware limits the parameter count for our Machine Learning Model, since a certain number of floating operations must be done for the model to make a prediction. This number is proportional to the number of parameters for a model. Better hardware such as a Nvidia Jetson Nano can provide more floating-point operations and support a more complex Machine Learning Model.

### 13.0 Integration and Implementation

Hardware wise, ensuring the parts were compatible and communicating with each other was vital. Thus, each component was wired together to confirm connection and programmability of the raspberry pi was possible. Also, the team would test the individual software compatibility with each other. From the transmitter to the server which would then connect with the app, several test cases were designed to ensure information was effectively passed from one device to another and accurately translated by the recipient. Below are the various tests that were performed:

13.1 Machine Learning Model Training and Prediction Capability

− Machine Learning Model is successfully trained and can make predictions on test images.
− Results: ML Model successfully identified most objects and spaces within the given images. The processing of the image data is sucessful converting the 30x40 RGB images into a 1d array. The training of the ML Model is sucessful stochastic gradient descent improving its %accuracy on each gradient descent step. The model is able to make predictions on the same 30x40 RGB images.

13.2 Machine Learning Model %accuracy requirement

− Machine Learning Models accuracy on real world data is greater than 85%.
− Results: The Machine Learning Models %accuracy was higher than 85% on parking lots that are mostly occupied. On parking lots where most of the spots are empty the %accuracy fell too 70% for the parking lot. The Machine Learning Model has difficulty detecting when spots are empty.

13.3 Machine Learning Model Overfitting Requirement

− Machine Learning Models (%error) between training and validation data is less then 5%.
− Results: The ML Model Overfitting %error between validation data accuracy and training accuracy was well below 5%. The graph below shows how the ML Model’s %accuracy over epochs of training, red being training set accuracy and orange being validation accuracy. There may be an issue with the validation data, and training data, being too similar since they take from the same training set because the ML Model’s %accuracy on real world data is low.

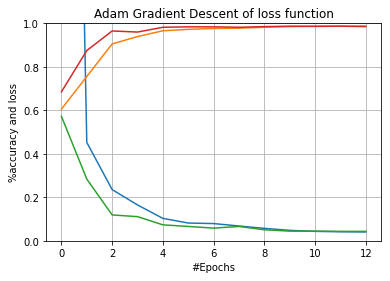
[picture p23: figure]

Figure 16: Adam Gradient Descent of loss Function

13.4 Transmitter/ Receiver Reliability

− 95% of data is communicated between the two devices
− Results: Over 95% of data was successfully communicated, initially without the antenna (the test setup) not every piece of data transmitted would successfully be read by the receiver. With the new set up (proper antennas) the transmitter/receiver was able to achieve a higher percentage of over 95%. The takeaway is that the transmitter and receiver chosen was sufficient for the needs of the project.

13.5 Transmitter/ Receiver Range

− Data is communicated between 2 devices at a minimum range
− Results: For the purpose of Digipark, the device located in the parking lot must be properly equipped to cover multiple sized parking lots. The determined range to be sufficient for the project is 500 meters. In this test case, the device was able to transmit and receive data just a little bit over 500 meters. An urban environment was used for this test, similar to that of a parking lot. The results prove that the transmitter and receiver can adjust to different sized parking lots, specifically in urban environments.

13.6 Camera Functionality

− Camera takes images
− Results: Images were successfully captured via camera module.

13.7 App Functionality

− Information Accurately Presented for User
− Results: Application successfully retrieved information from server and translated that data into an understandable form of information for the user. App is heavily dependent on server being operational for most functionality but still effective.

### 14.0 Comments and Conclusion

The development of Digipark was a challenging yet rewarding experience for our team. We encountered technical issues such as error code problems and securing a suitable testing location, but we worked collaboratively and persistently to overcome these obstacles. Our efforts led to the successful integration and thorough testing of all hardware and software components, including tests for machine learning model capability, accuracy, overfitting, transmitter/receiver reliability, and range. Throughout this project, we gained valuable insights into the importance of effective communication, collaboration, and thorough testing in engineering design. Ultimately, the development of Digipark demonstrated the practical application of engineering design and testing in addressing real-world problems

Comment on Machine Learning Model. The original plan for the project was to train and use a convolutional neural network as our Machine Learning Model to analyze images taken of parking lot. An effort was made to learn Tensor Flow and Keras API in order to do this. A few low parameter convolutional neural networks were trained on the same dataset as the Multi-Layer-Perceptron model. These models did not perform better than the Multi-Layer-Perceptron, most likely again from the dataset not generalizing to all parking lots and low parameter count and because of this they were not utilized. At the tech symposium a pretrained YOLO convolutional neural network was implemented that had a higher parameter count ,but could do object detection as well as object classification. This would be the Machine Learning Model used for the next version of the project. The model is a fully convolutional neural network which means it only utilizes convolution layers of neurons and pooling layers and can take in images of various sizes. Below is image of it working on a set of hot wheels cars and a diagram of the basic architecture of the YOLO CNN model. The diagram made and the use of this Machine Learning model came from the original paper on the YOLO model from Redmon, Joseph reference 6. The convolutional neural network models were developed using the TensorFlow documentation reference 11.

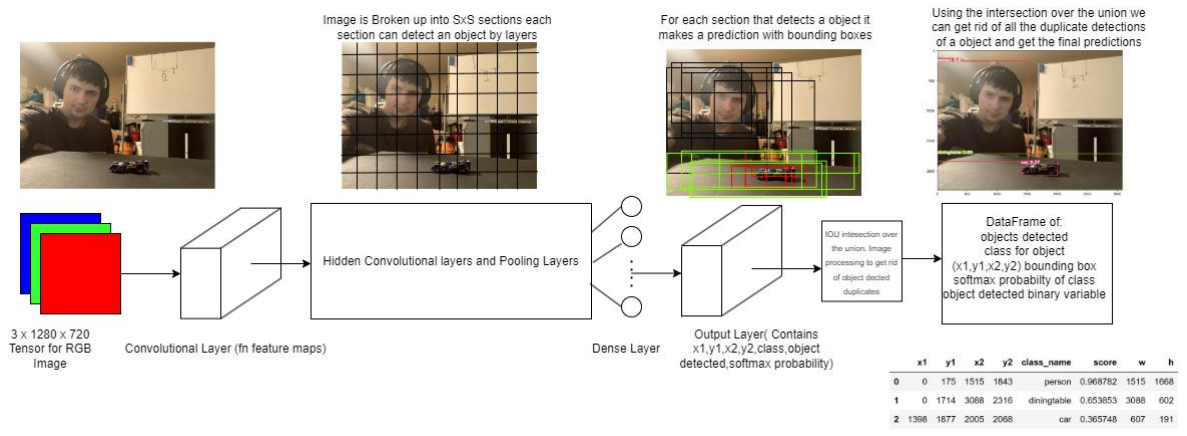
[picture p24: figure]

### 15.0 Team Members

15.1: Preston Ott, Design Lead - Contributed across each module of the project. The Machine Learning Model data processing and training, the framework and code for the parking app, entire program for the camera and Machine Learning Model, development of CAD files for 3d printed enclosure/case, 3d printing of each part for the enclosure/case, machine shop fabrication of the platform. Integration of the transmitted and scanner. Integration of the server and the app. Test cases for the ML Model, conceptual work and engineering analysis for the parking app, Machine

Learning Model, app server, 3d printed enclosure, optics of the camera. Research was also done on Machine Learning to improve models. Pretrained Yolo Convolutional Neural Network integrated into main program for Machine Model and camera for tech symposium presentation.

15.2: Younes Younes, Embedded Design Engineer - Contributed to various aspects of the project, including the creation of the schematic design, assembly of the prototype, platform case assembly, and the development of transmitter/receiver test cases. Researched similar projects.

15.3: Joshua Swanner, Secretary and App developer – Kept times in meetings and co-devolved application for user interaction. Also, tests various application functions alongside other aspects of the projects and researched similar projects for initial inspiration.

15.4: Joshua Moya, App developer and prototype - Assisted with the app that was used up until version 3 of the app. Continued to then work on the 3D model for the case and made the case for the prototype along with the mount for the prototype. Assembled the final prototype and developed camera test cases.

15.5: Luis Santillan, Embedded Design Engineer – Contributed to a lot of the hardware needs, from schematic development and selection of parts. Had the largest influence on the transmitter and receiver aspect of the project. Helped write the code for this module and integrate and implement with the other parts of the project, such as the ML model and server programs.

### 16.0 References

"IEEE Recommended Practice for Radio Frequency Safety Programs, 3 kHz to 300 GHz," in IEEE Std C95.7-2014 (Revision of IEEE Std C95.7-2005) , vol., no., pp.1-58, 8 Aug. 2014, doi: 10.1109/IEEESTD.2014.6874474.

"IEEE Standard for Radio-Frequency Energy and Current-Flow Symbols," in IEEE Std C95.2-2018 (Revision of IEEE Std C95.2-1999) , vol., no., pp.1-28, 5 Oct. 2018, doi: 10.1109/IEEESTD.2018.8486934.

"IEEE Guide for EMF Exposure Assessment of Internet of Things (IoT) Technologies and Devices," in IEEE Std 1528.7-2020 , vol., no., pp.1-90, 11 Jan. 2021, doi: 10.1109/IEEESTD.2021.9319817.

Cleverciti sensor. Cleverciti. (2012). Retrieved May 2, 2023, from https://www.cleverciti.com/en/innovations/cleverciti-sensor

ATTAR, O., HASSON, O., & NAAMANI, A. (2021, May 20). a training system for automatically detecting parking space vacancy.

Redmon, Joseph, et al. “Homes.Cs.Washington.Edu.” Https://Homes.Cs.Washington.Edu/, June 2016, homes.cs.washington.edu/~ali/papers/YOLO.pdf.

Zhang, JAX. “What’s the Mean of FOV, HFOV, VFOV, and DFOV for Security Cameras? " Kallglow.” KallGlow, 9 Apr. 2022, www.kallglow.com/whats-the-mean-of-fov-hfov-vfov-and-dfov-for-security-cameras/. (http://www.kallglow.com/whats-the-mean-of-fov-hfov-vfov-and-dfov-for-security-cameras/)

Authors, The Kivy. “Welcome to Kivy¶.” Kivy, 2022, kivy.org/doc/stable/.

Scikit-learn: Machine Learning in Python, (https://jmlr.csail.mit.edu/papers/v12/pedregosa11a.html) Pedregosa et al., JMLR 12, pp. 2825-2830, 2011.

-Learn, Sci-Kit. “Learn.” Scikit, 2011, scikit-learn.org/stable/.

Foundation, Raspberry-Pi. “Raspberry Pi Documentation.” Camera Software, 2012, www.raspberrypi.com/documentation/computers/camera_software.html#libcamera-vid-2.

Developers, Google. “API Documentation : Tensorflow V2.12.0.” TensorFlow, 2021, www.tensorflow.org/api_docs.

Hallard, Charles. “Hallard/Radiohead: Radiohead Packet Radio Library for Embedded Microprocessors.” GitHub, github.com/hallard/RadioHead. Accessed 10 May 2023.

Géron, Aurélien. Hands-on Machine Learning with Scikit-Learn, Keras and Tensorflow: Concepts, Tools and Techniques to Build Intelligent Systems. O’Reilly, 2020.

Faruque, Sarker M O, and Sam Washington. Learning Python Network Programming: Utilize Python 3 to Get Network Applications up and Running Quickly and Easily. Packt Publishing Limited, 2015.

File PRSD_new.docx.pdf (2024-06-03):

For: UTSA Senior Design | Revision: X2
Project: OYSMS DigiPark | Page: 1 of 16
Date: 1/25/2023
Prepared by: Preston Ott, Younes Younes, Joshua Swanner, Joshua Moya, Luis Santillan Instructor: Johnathan Votion Ph.D & August Allo

# Product Requirements And Specifications Document (PRSD) OYSMS DigiPark

## Approvals

Title | Print | Signature | Date
OYSMS Digi Park | Younes Younes | | 1/25/2023
OYSMS Digi Park | Joshua Swanner | | 1/25/2023
OYSMS Digi Park | Luis Santillan | | 1/25/2023
OYSMS Digi Park | Preston Ott | | 1/25/2023
OYSMS Digi Park | Joshua Moya | | 1/25/2023

## Revision History

Revision | Summary of Change | Originator
X0 | New Document | UTSA-ECE
X1 | Clarification | UTSA-ECE
X2 | Revisions to accommodate the scope of the product | UTSA-ECE

OYSMe requirements andS DigiPark: Product Requirements Document (version 1.0)

Date: 1/25/2023
Prepared by: Preston Ott, Younes Younes, Joshua Swanner, Joshua Moya, Luis Santillan Instructor: Johnathan Votion Ph.D & August Allo

### 1. Introduction

This document contains the system requirements for OYSMS DigiPark. These requirements have been derived from several sources, including regulations from the University Parking and Traffic Rules & Regulations at UTSA and competing products as a guideline for our project.

### 1.1 Purpose of This Document

This document is intended to guide development of OYSMS DigiPark. It will go through several stages during the course of the project:
1. Draft: The first version, or draft version, is compiled after requirements have been discovered, recorded, classified, and prioritized.
2. Proposed: The draft document is then proposed as a potential requirements specification for the project. The proposed document should be reviewed by several parties, who may comment on any requirements and any priorities, either to agree, to disagree, or to identify missing requirements. Readers include end-users, developers, university faculty, course instructor, and any other stakeholders.
3. Validated: Once the various stakeholders have agreed to the requirements in the document, it is considered validated.
4. Approved: The validated document is accepted as an appropriate statement of requirements for the project. The developers then use the requirements document as a guide to implementation and to check the progress of the project as it develops.

### 1.3 Scope of the Product

The problem of high traffic parking lots or finding an open parking space is one of the most significant issues faced by the drivers in a parking lot. Various solutions have been proposed by different companies. Our proposed solution is a mobile application based on the development of a pre-mapped parking lot and a scanner that detects free spots in a parking lot. The mobile application is highly efficient and offers distinct features such as real-time updates and statistics of the free parking spaces along with the closest free spots based on the user’s location.

### 1.4 Case for the Product (Need)

A problem that has been an issue for some time now is the parking around campus. Finding a parking spot on campus can be tough because there are so many people trying to go to class, and with a limited amount of spots it is hard to know if other parking lots have open parking spots. This will help many people find parking on campus with little to no struggles. Approximately, parking costs 73 billion dollars a year and Americans spend 17 hours per year searching for a parking spot. All businesses and buildings that have parking lots will benefit from this solution because customers avoid shops due to inadequate parking space. All people who own or use a motor vehicle will benefit from this solution through fuel and time savings.

Date: 1/25/2023
Prepared by: Preston Ott, Younes Younes, Joshua Swanner, Joshua Moya, Luis Santillan Instructor: Johnathan Votion Ph.D & August Allo

### 2. General Description

The problem we are going to solve is finding a parking space in a crowded parking lot, which was brought to our attention by our groupmate Preston on the first day of school at UTSA. In a large parking lot, it can be difficult to navigate and locate an open space and if an open space is obscured, you have no way of telling where it is. We want to solve this unawareness of all the open parking spaces in a parking lot so a driver can locate an open space obscured from view or an open space that could be thousands of feet away. The way we will accomplish this is by placing several devices in a parking lot to detect which parking spots are open/taken. We will have an app that accompanies this which the user will use to find an open parking spot.

### 2.1 Product Perspective

The idea for OYSMS DigiPark came from Preston Ott on the first day of school when the realization came to him that the parking situation at UTSA was a problem. Digipark serves to offer an efficient solution to people’s problems when finding a parking spot in a parking lot. The project is being developed by our OYSMS group of 5 for senior design II at UTSA and is currently being funded by Mr. Chad Webster. On completion, anyone with a phone and a car will benefit from the project when searching for a parking spot.

### 2.2 Product Functions

There are two parts to the project, A device that goes into the parking lots and an app for smartphones. The device will detect which parking spots in a designated parking lot are taken or empty. The app is the main function that the users will be interacting with. The app will include a straightforward map of the parking lot, provide real time updates of new open parking spots within a parking lot, give the percentage of open spots available in a lot, give data on the availability of parking in a given parking lot throughout the day, portray the user’s location within the parking lot, and highlight the nearest available parking spots.

### 2.3 User Characteristics

The expected demographic for the product is anyone with a car and a smartphone. The reason they would use the product is if they are having trouble looking for a parking spot in a busy parking lot. The app would help them in this search or help them decide to park in a low traffic parking lot. Problems may include navigation of the app if the user is not well versed in using their smartphone and applications on it.

### 2.4 General Constraints

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

The main constraint of the application are the guidelines placed on by the app stores and the capabilities of the programming language being used to develop the app. For the device there are rules and standards given by the FCC when transmitting radio frequencies. Another constraint would be communicating the devices' information to the server running our application.

### 2.5 Assumptions and Dependencies

An assumption involving the device is the power supply, as of now the device will be battery powered and will need maintenance when switching batteries, unless an indefinite power supply were to be provided. Another assumption of the device is the distance from the furthest parking lot device and the server will not exceed 1km as the RF transmitter will be approximately limited to that range. It is assumed that UTSA can help us in setting up the device in the parking lot to assist with testing and upon product completion.

### 2.6 Objectives:

1.) Test each part, and assemble (scanner and transmitter system) circuit and develop program for (scanner and transmitter system)
1. Find or Develop code or circuit test to test each component individually
2. Build subsystems of circuit, develop test for subsystems and verify subsystems
| work
3. Assemble complete (scanner and transmitter system), write code for test, test
| complete circuit can take images and rotate camera to desired positions.
4. Develop Final program to control (scanner and transmitter system) and test it. 2.) Develop program for server scanner communication
5. Determine python libraries and resources for server (scanner and transmitter)
| system communication program and create software flow chart for program.
6. Develop a basic server (scanner and transmitter system) communication program
| to transmit and receive basic strings of data and test it.
7. Improve server (scanner and transmitter system) communication program to
| transmit and receive formatted messages.
8. Improve server program to process images, remove noise, reformat image to
| specific dimensions, and compress image.

3.) Develop Machine Learning Model for car in parking space detection (Convolutional Neural Network most likely)
1. Determine type of Machine Learning Model and python libraries/resources for
| model
2. Find or create labeled data to train Machine Learning models with.
3. Write the program for Machine Learning model for training and testing.
4. Train Machine Learning Model and test it on labeled data.

Date: 1/25/2023
Prepared by: Preston Ott, Younes Younes, Joshua Swanner, Joshua Moya, Luis Santillan Instructor: Johnathan Votion Ph.D & August Allo
5. Improve Machine Learning model until classification accuracy threshold is
| reached.

4.) Develop parking lot Mobile app
1. Determine all libraries/ modules needed to develop app and create detailed
| software flow chart for the app.
2. Write program for app for testing purposes only to run on PC or laptop. Basic
| program should include basic GUI and server client communication. Test app with (scanner and transmitter system) and server.
3. Improve app develop user-based GUI, Parking lot map from received data,
| improved menu. Test app on a mobile device such as iPhone or android phone.
4. Deploy the app into a store and test the deployed app.
5. Improve the app by adding navigation feature for mobile device using its GPS
| module and statistics on parking lot data feature and test new features.

(Scanner and Transmitter system Block Diagram)


(Scanner and Transmitter and ML Model Program Software Flow Chart)

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

(Software Flow Chart of Server and (Scanner and Transmitter System) Communication Program and Client Communication Program)

(Software Flow chart for Parking app Program)

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

●


### 2.7 Plan

High Level Task Description:
- Create a working autonomous scanner system that can be implemented in a parking lot.
- Create a working transmitter/server system to communicate with the autonomous scanner system.
- Create a Machine Learning Model for classifying parking spaces as empty or unoccupied.
- Create a mobile app to display information on parking lot utilizing scanner system and transmitter/server system.
Principles and Theories to be used:
- Wireless communication theory
- Machine Learning theory
- Wired Communication
- Image Processing
- Robotics
- Mobile app development and design
- Optics
Complications:
- Wireless transmission of Strings of data.How to Handle noise in transmission.
- Finding/creating labeled data to train Machine Learning Model.
- Client server communication for mobile app.
Design approach/methodology:
- Developing Circuit Schematics before Implementation.
- Developing fundamental prototype programs for testing feasibility and proof of concept.

Date: 1/25/2023
Prepared by: Preston Ott, Younes Younes, Joshua Swanner, Joshua Moya, Luis Santillan Instructor: Johnathan Votion Ph.D & August Allo
- Develop subsystems of circuit and test them independently.

Implementation of Project:
- Modular design of scanner circuit.
- Modular design of server app.
- Modular design of mobile app.
- Independent development of machine learning model.
- Server and Scanner Communication is Separate from Client Server Communication.

Validation and Verification:
- Machine learning models will be validated with test data and will use cross validation for overfitting/underfitting avoidance (Multiple machine learning models will be trained).
- Classes and functions for programs independently tested with preset inputs and expected outputs.
- Individual circuit component testing with test programs.
- Individual circuit module test.
- Circuit modules integration testing.
- Wireless communication test between server and transmitter under different conditions.
- Early prototype testing for all major engineering requirements in a small parking lot.

### 2.8 Schedule Requirements

Overview:
The schedule requirements are broken down into seven segments. Each segment depends on the other being completed. The first segment is the high-level design/ preparation/choice stage. This stage picks all software and hardware components and makes high level design decisions. This stage will take 2 weeks to complete from the end of fall semester. The second is testing individual components. This stage will develop and test individual circuit components and software components as well as assemble and test the different modules of circuit. This stage will take about 1 month to complete during winter break. The third stage is the early prototype stage. This consists of assembling our bare hardware and software modules to make a very basic prototype to test all major functionality of our project such as basic transmission of data, taking images of parking lot autonomously with scanner, Machine Learning model car positioning and more. This stage will take about 2 and a half weeks to complete during winter break. The fourth stage is testing early prototype stage. This stage consists of testing the early prototype and identifying all bugs in each module and debugging them and improving the server and scanner communication to transmit images. This stage will take about a month to complete during the start of the spring semester. The fifth stage is the improvement stage. This stage will improve on the basic prototype to include more functionality in mobile app and server program and transfer scanner/transmitter circuit into a PCB or perf board with a 3d printed case. These improvements will also be tested in this stage. This stage will take about a month to complete during the spring semester. The sixth stage is the testing and finalizing stage. This stage consists of testing and

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

debugging the improved prototype in an actual parking lot. This stage will finalize the 3 programs for the project and deploy our app into an app store. This stage will take about 3 weeks to complete during spring semester. The seventh and last stage is the preparation stage. This stage consists of preparing project for tech symposium and final testing/debugging of the final prototype. This stage will take about 3 weeks to complete during spring semester.


Gantt Chart:

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


### 3. Specific Requirements and Specifications

This section of the document lists specific requirements and specifications for OYSMS DigiPark. Requirements and specifications are divided into the following sections:
1. User requirements and specifications. These are requirements and specifications written from the point of view of end users, usually expressed in narrative form.
2. System requirements and specifications. These are detailed requirements and specifications describing the functions the system must be capable of doing.
3. Interfac specifications. These are requirements and specifications about the user interface, which may be expressed as a list, as a narrative, or as images of screen mock-ups.

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

### 3.1 User Requirements and Specifications

3.1.1 User interface
The user interface will be available from a mobile app that the user will be able to use on their cellular device. They will be able to look at the parking spaces available and the parking lots that are available and the ones that aren’t available.

3.1.2 Ergonomics
This product will be in the air above the reach of anyone, so that it will be able to scan the designated area. This will make sure it is not in anyone’s way.

3.1.3 Training or skills required
Technical understanding and experience of operating a smart device is required for the app. To be able to use the app you just must know how to use your phone. Being able to navigate through the app without no trouble. You also need to be able to drive and/or have the navigation skills to get to the designated spot.

### 3.2 System Requirements and Specifications

3.2.1 Physical Characteristics
− Raspberry pi 4
o Weight: | 46 g
o Dimensions: | 85.6mm x 56.5mm
− Transmitter
o Weight: | 15.4 g
o Dimensions: | 0.63x0.63x0.07 in
− Camera
o Weight: | 34 x 24 mm
o Dimensions: | 20 g
3.2.2 Material Requirements − 3-D Printed case
3.2.3 Electrical Requirements − Raspberry pi 4:
o Power: 5V DC, 2.5A
o Operating System: Python
o Operating Temperature: 0-50 degrees C 3.2.4 Abilities
− Take an image and processing that image
3.2.5 Limitations
− Not enough range to cover every parking lot simultaneously − Wi-Fi signal not strong enough
3.2.6 Equipment or materials required to use the product

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

− Smart Phone
− Mobile App installed
3.2.7 Equipment interface requirements
− SD memory storage reading capabilities 3.2.8 Handling and storage requirements
− Needs to be up high in the air
3.2.9 Cleaning and Sterilization
− Cleaning the camera is going to be essential for us to get a clear picture of the parking lot 3.2.10 Product maintenance and serviceability
− Cleaning the camera to get a clearer picture
− Fixing the bugs of the app as we go along
− Wi-Fi needs to be available
3.2.11 Operating parameters
− OV5642
o Power Supply: 3.3V - 5V
o Pixel Size: 1.4µm x 1.4µm o Temperature: -10°C～+55°C − Raspberry pi 4
o Power Supply: 5V DC, 2.5A o Temperature: 0-50 degrees C − RFM95
o Power Supply: 3.3V
o Temperature: -55°C～+115°C
3.2.12 Repeatability and reproducibility
− The project is going to be able to refresh and be able to repeat each process every 15 seconds. If the camera is going to be clean, then there should be no problems.
3.2.13 Reliability
− Depending on the weather conditions and other conditions, this product will be reliable on any day. Up to the user to refresh the app to see availability.
3.2.14 Mechanical safety features
− 3-D printed case
3.2.15 Electrical safety features
− Raspberry Pi 4
− Wires
− Transmitter
− Camera
− PCB

### 3.3 Interface Requirements and Specifications

Access and translation between the digital camera and transmitter should be monitored by our microcontroller. For the sake of consistent image upload to a database server which will translate said information into a readable form for our users. From this, our users will interact

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

with the given parking information via an application that will take user input and guide them to their desired location. The device will be detached from the elevated location for maintenance if physical repairs are necessary and updates to the server can be done at a separate location.

### 3.4 Environmental Conditions

3.4.1 Temperature:
3.4.1.1 Operating: -20°C to 50°C
3.4.1.2 Storage: -25°C to 60°C
3.4.2 Humidity
3.4.2.1 Operating: 5-90% non-condensing 3.4.2.2 Storage:
- 5-90% non-condensing
3.4.3 Shipping, transportation vibration
- NA
3.4.4 Pressure and Altitude
- Maximum External Pressure: 1 atm
- Altitude: 5-10 meters
3.4.5 Electromagnetic Interference
- TBD
3.4.6 Electrostatic Discharge
- N/A
3.4.7 Impact Resistance
- N/A

### 3.5 Manufacturing

3.5.1 Cost
- Electronic Components:
- RFM95/96/97/98: $20-$30
- Raspberry Pi 4: $20-$40
- OV5642 Digital Camera $50-$100
- Other Materials:
- Weather Resistant Filament $20-$25per kg 3.5.2 Environmental requirements for production
- Source and Containment
3.5.3 Raw materials and suppliers
- Weather Resistant Filament for 3D Printing 3.5.4 Test methods, standards
- Weather Durability tests
- Software/Image tests
- Compatibility tests

### 3.6 Packaging

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

3.6.1 Packaging configurations
- Appropriately Sized Pelican Case
3.6.2 Packaging materials
- Case full of packing foam
3.6.3 Special shipment requirements
- Special protection for camera lens

### 3.7 Labeling

3.7.1 Detail intended use, warning, directions for use, cleaning, expiration date
- Intention – Parking Lot Monitoring and Analysis
- Warning – Fragile Components
- Directions – For Setup
3.7.2 Identify the target audience for labeling
- Client installations and security
3.7.3 Language requirements
- English

### 3.8 Regulatory

3.8.1 Clinical trials
- N/A
3.8.2 Submission type
- N/A
3.8.3 CE mark
- N/A
3.8.4 US and international standards
- RF Radio Frequency used for Image Transmission
- Pspice Simulation Software
- Graphical User Interface Design Standards
- Federal Communications Commission Standards for Communication Equipment 3.8.5 Patent issues
- None
3.8.6 Existing technology to avoid
- None

### 4. Appendices

N/A

### 5. Glossary

OYSMS: Team name

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

UTSA: University of Texas at San Antonio
FCC: Federal Communications Commission
RF: Radio Frequency
PC: Personal Computer
GUI: Graphical User Interface
GPS: Global Positioning System
Pspice: A design and simulation environment that helps evaluate functionality of analog circuits. PCB: Printed Circuit Board

### 6. References

- University Parking and Traffic Rules & Regulations
- OmniVision OV5642 Datasheet
- Raspberry Pi 4 Model B Datasheet
- HopeRF RFM95/96/97/98(W) Datasheet

### 7. Index

N/A

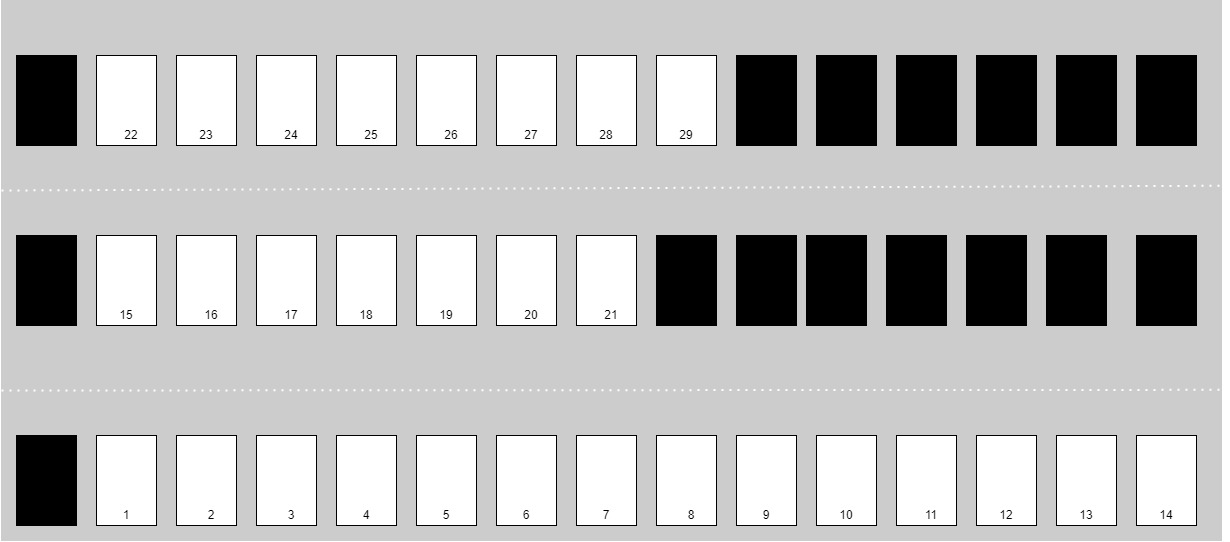
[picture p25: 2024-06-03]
Parking_Lot_Application/Empty_Maps/UTSA-Map.jpg

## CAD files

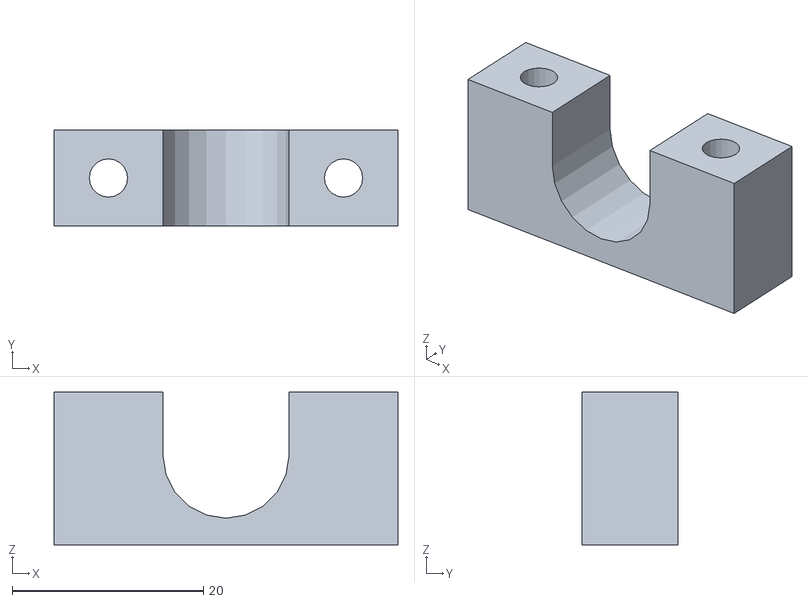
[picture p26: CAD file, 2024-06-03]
CAD-Models/Antenna_Mount/Antenna Mount (7).stl
36.0 x 10.0 x 16.0

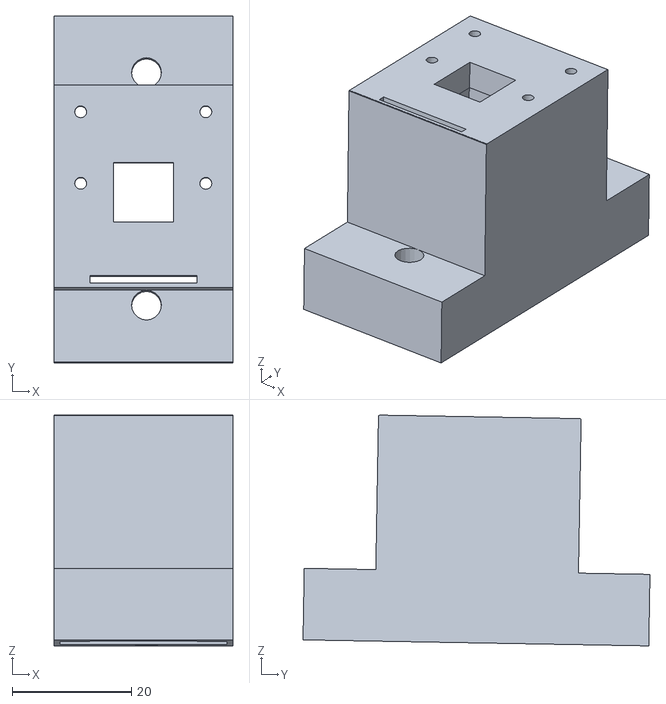
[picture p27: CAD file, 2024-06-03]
CAD-Models/Camera-Mount2-Design-2/Camera Mount-2.3 (1).stl
30.0 x 58.2 x 38.7

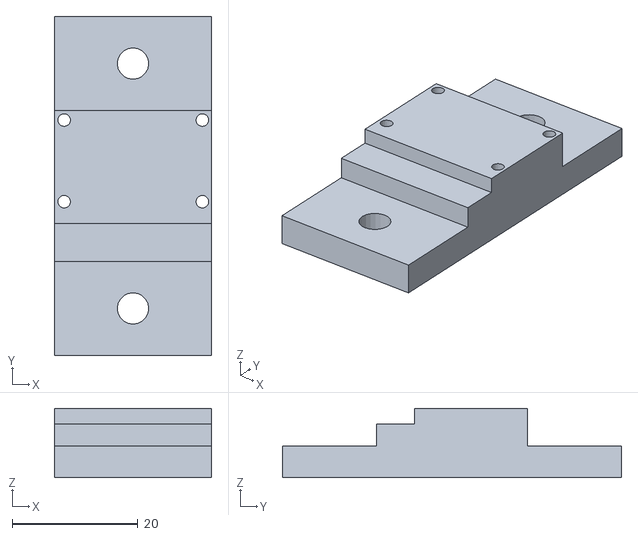
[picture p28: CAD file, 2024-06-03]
CAD-Models/Camera_Mount/Camera Mount (5).stl
25.0 x 54.0 x 11.0

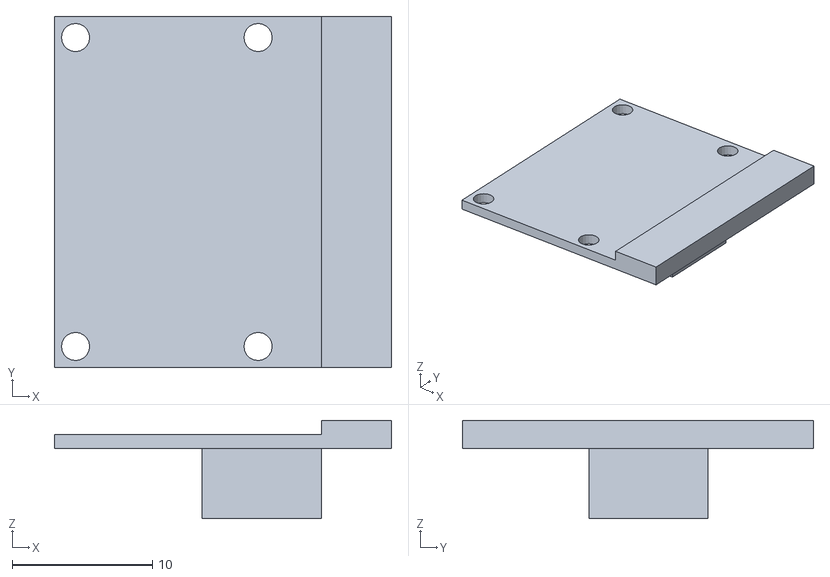
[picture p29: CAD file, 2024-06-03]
CAD-Models/OV5647_Camera_Solid/OV5647_Camera_Solid.stl
24.0 x 25.0 x 7.00

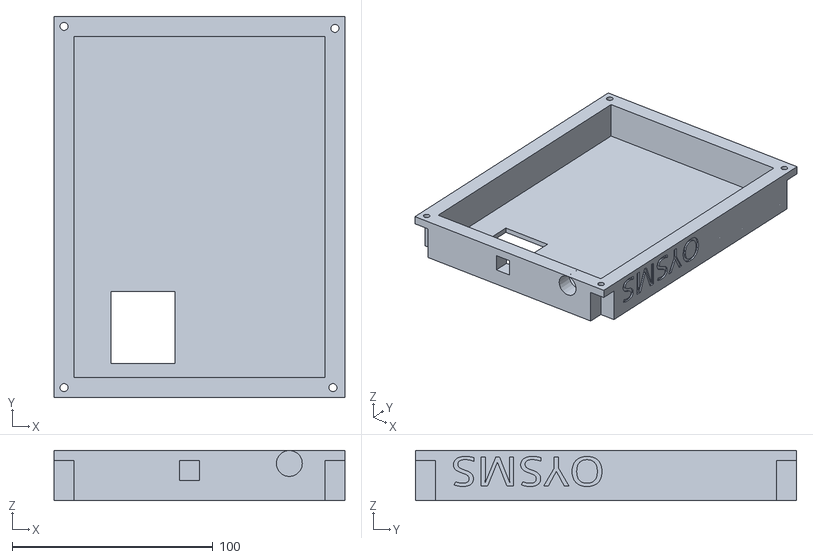
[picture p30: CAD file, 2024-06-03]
CAD-Models/Platform-Case-Design-2/Platform_Case (3).stl
145.0 x 190.0 x 25.0

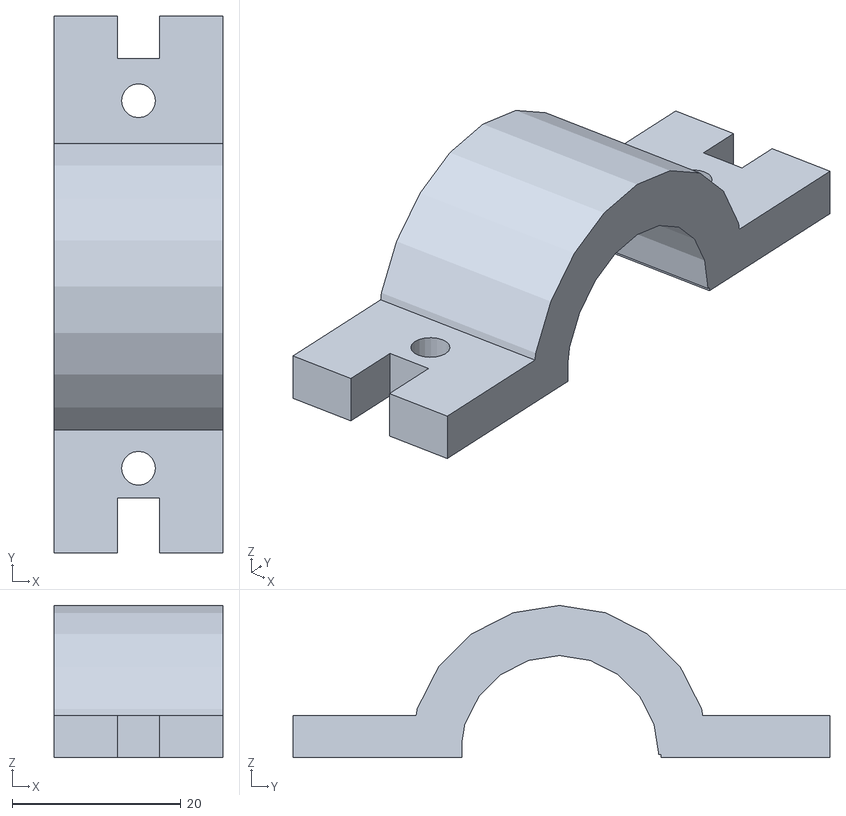
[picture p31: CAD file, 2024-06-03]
CAD-Models/Platform-Mount-Coupler/PVC-Pipe-Mount-Coupler-Tightner.stl
20.0 x 63.5 x 18.0

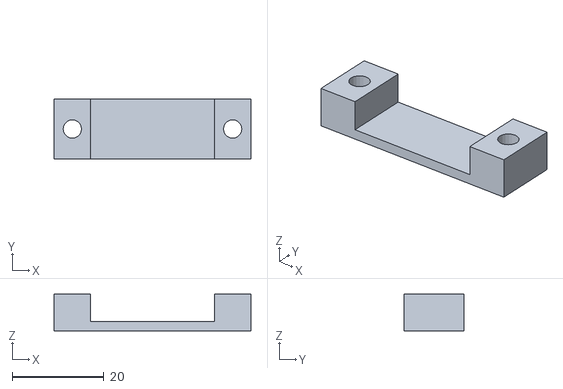
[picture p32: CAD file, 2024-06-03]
CAD-Models/Transmitter_Mount/Transmitter Mount (4).stl
43.0 x 13.0 x 8.00

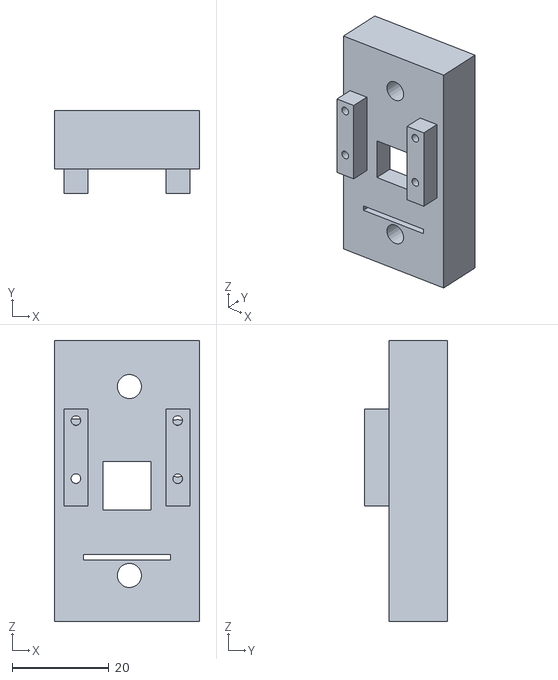
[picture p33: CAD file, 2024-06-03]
CAD-Models/Camera-Mount2-Design-2/Camera Mount-2.1.stl
30.0 x 17.0 x 58.0

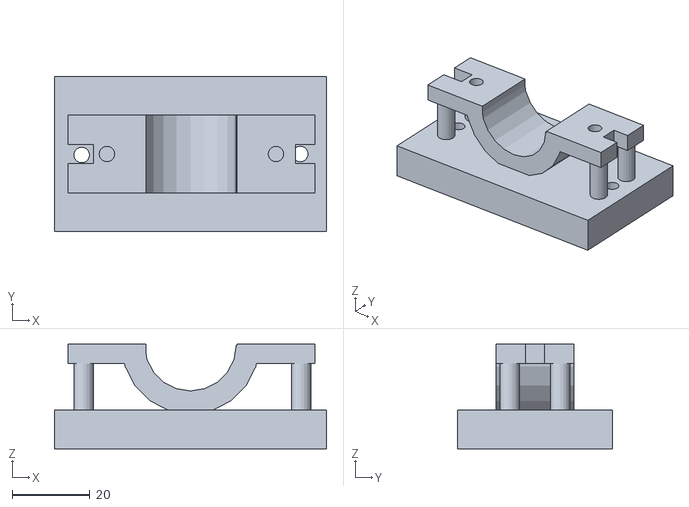
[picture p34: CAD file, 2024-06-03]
CAD-Models/Platform-Mount-Coupler/PVC-Pipe-Mount-Coupler-Base.stl
70.0 x 40.0 x 27.0

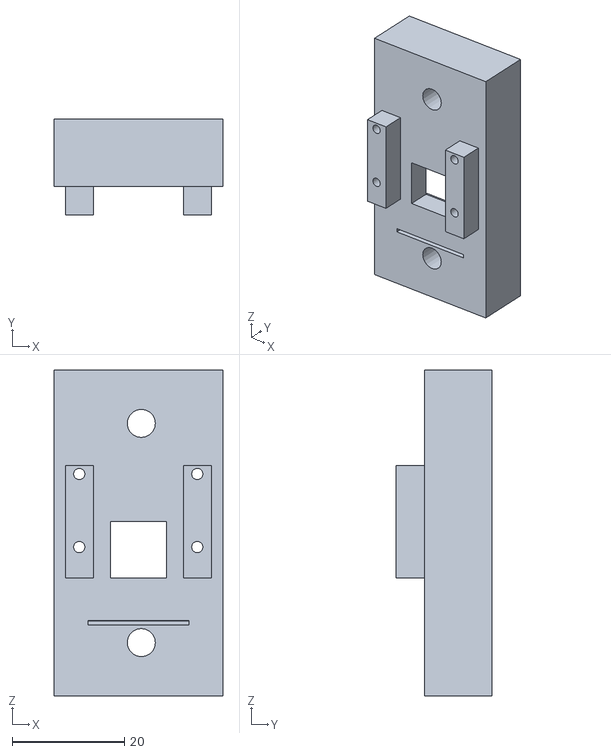
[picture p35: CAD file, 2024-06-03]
CAD-Models/Camera-Mount2-Design-2/Camera Mount-2.stl
30.0 x 17.0 x 58.0

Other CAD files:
CAD-Models/Final_Platform/Platform1 (v2~recovered).f3d

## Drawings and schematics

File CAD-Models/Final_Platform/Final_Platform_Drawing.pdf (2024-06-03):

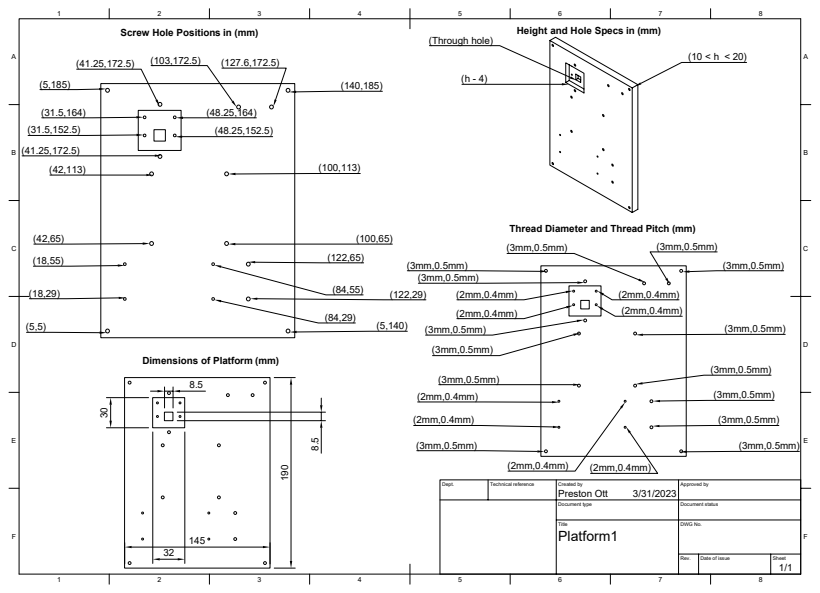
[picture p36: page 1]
Dept.; Technical reference; Created by; Approved by; Document type; Document status Title; DWG No. Rev.; Date of issue; Sheet 3/31/2023; Platform1; Preston Ott

Screw Hole Positions in (mm)
(Through hole) 30

Height and Hole Specs in (mm)

Thread Diameter and Thread Pitch (mm)

Dimensions of Platform (mm)

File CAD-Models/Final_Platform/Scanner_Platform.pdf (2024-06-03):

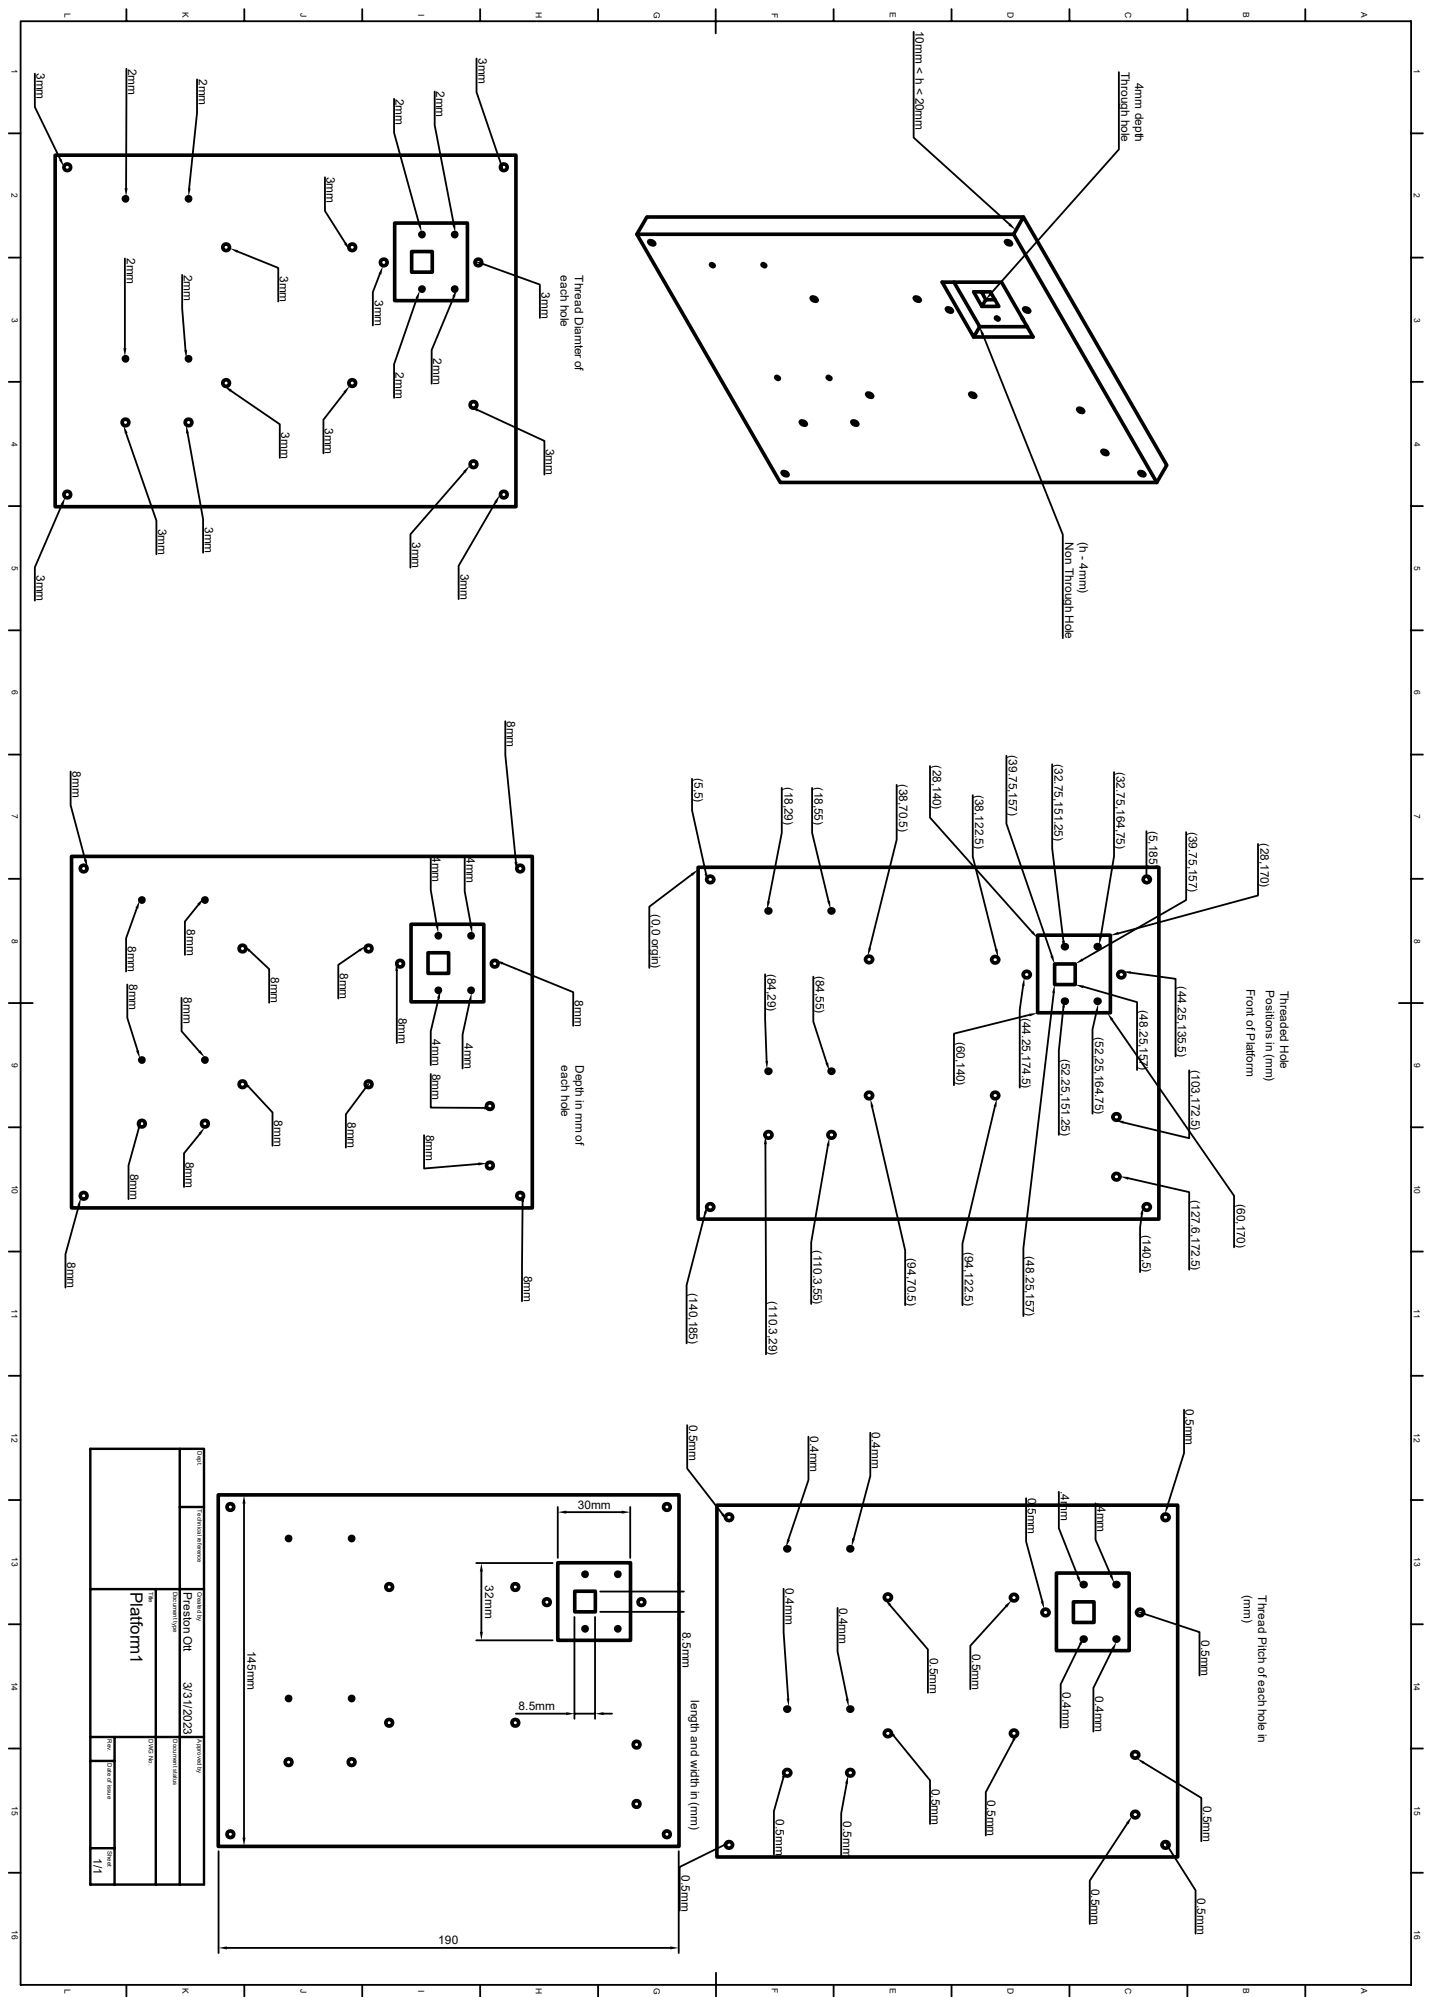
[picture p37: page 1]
190 ¹⁴⁵mm; length and width in (mm); Non Through Hole ⁽h - 4mm) 10mm < h < 20mm; 4mm depth Through hole (39.75,157) (48.25,157)

2 1 3 4 5 6 7 8 9 10 11 12 13 14 15 16 2 1 3 4 5 6 7 8 9 10 11 12 13 14 15 16 LKJIHGFEDCBA LKJIHGFEDCBA Dept. Technical reference Created by Approved by Title DWG No. Document type Document status Rev. Date of issue Sheet 3/31/2023 1/1 Platform1 Preston Ott (5,185) (140,5) (44.25,135.5) (44.25,174.5) (38,122.5) (38,70.5) (94,122.5) (94,70.5) (18,29) (18,55) (84,55) (84,29) (110.3,55)(110.3,29) (103,172.5) (127.6,172.5) (5,5) (140,185) (32.75,164,75) (52,25,164.75) (52.25,151.25) (32.75,151.25) Front of Platform Positions in (mm) Threaded Hole 8mm (0,0 orgin) 8mm 8mm8mm 8mm 8mm 8mm 8mm 8mm 8mm 8mm8mm 8mm 8mm 8mm8mm 4mm 4mm 4mm 4mm 8mm 8mm each hole Depth in mm of 3mm 3mm 2mm 2mm 2mm 2mm 2mm2mm 2mm2mm 3mm3mm 3mm 3mm 3mm 3mm 3mm 3mm 3mm 3mm 3mm 3mm each hole Thread Diamter of 0.5mm 0.4mm .4mm .4mm 0.4mm 0.5mm 0.5mm 0.4mm 0.4mm 0.4mm 0.4mm 0.5mm 0.5mm 0.5mm 0.5mm 0.5mm 0.5mm 0.5mm 0.5mm 0.5mm 0.5mm 0.5mm (mm) Thread Pitch of each hole in

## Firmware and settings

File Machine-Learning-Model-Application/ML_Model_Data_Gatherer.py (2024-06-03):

#This is integration of the Parking_Data_Gatherer and the ML_Model, this program will periodically capture images
#, segement them using a mask, run the ML Model on each segement, and draw the predictions on the original image
#Preston Ott, OYSMS Digi-Park



#Importing the libraries we'll need
import os
from PIL import Image as im
import time
import openpyxl as xl
from picamera2 import Picamera2, Preview
import numpy
import threading
import pickle
import cv2
import pandas
import sklearn



#Importing the libraries we'll need to make the app
import kivy
import sqlite3
from PIL import Image as im
from PIL import ImageDraw
import os
import math
from kivy.core.window import Window
from kivy.app import App
from kivy.uix.widget import Widget
from kivy.uix.label import Label
from kivy.uix.button import Button
from kivy.core.window import Window
from kivy.uix.floatlayout import FloatLayout
from kivy.uix.gridlayout import GridLayout
from kivy.uix.boxlayout import BoxLayout
from kivy.uix.relativelayout import RelativeLayout
from kivy.uix.image import Image
from kivy.uix.textinput import TextInput
from kivy.uix.textinput import TextInput
from kivy.clock import Clock

################################################################################################################
#Here we define function fetch_mask to fetch mask from a csv file for our particular parking lot
def fetch_mask(path,numspots):
    
    #Fetching the specific csv file
    book1 = xl.load_workbook(path)
    
    #Now we get the active worksheets in this workbook
    sheet1 = book1.active
    
    #Now we get make a numpy array to store the mask
    mask_lot = numpy.zeros((numspots,4))
    
    #Now we store the mask in the numpy array
    for i in range(numspots):
        mask_lot[i,:] = [sheet1.cell(i+1,1).value, sheet1.cell(i+1,2).value, sheet1.cell(i+1,3).value, sheet1.cell(i+1,4).value]
    
    #Now we return the mask we made
    return mask_lot
#Here we define a function that will segment a image into individual spots using the mask
def segment_image(mask,image,image_path):
    
    #First we create an array to store the images
    image_array = []
    os.chdir(image_path)
    park_lot_image = image
    
    
    #Now we segment the (image) into individual spots and scale them to (30x40) pixels
    print(mask.shape[0])
    for i in range(mask.shape[0]):
        #Extracting the ith image
        image_array.append(park_lot_image.crop(box = (mask[i,:])))
        
    #Now we resize the images to be (30x40) pixels
    for j in range(len(image_array)):
        #Resizing the image to be (30x40) pixels
        image_array[j] = image_array[j].resize(size = (30,40))
        
    #Returning the list of images
    return image_array
    
#Here is a function that will take in a image object and apply the mask to it
def mask_image(mask,image):
    
    #Defining a image to draw on
    im2 = ImageDraw.Draw(image)
    
    #First we go into a loop size of mask
    for i in range(mask.shape[0]):
        rect = tuple(mask[i,:])
        im2.rectangle(rect,fill = None,outline = (0,255,0))
    
    #Now we return the image object
    return image
        
    
        

#Now we make a function that will save a list of images to the unlabeled data folder
def save_images(path,image_list):
    
    #First we change our cwd to path
    os.chdir(path)
    
    #Now we get the list of items in folder
    list = os.listdir()
    
    #Now we save all the images and give them ordered names
    for i in range(len(image_list)):
        #Making name for image
        name = "image" + str(len(list)+i) + ".jpg"
        image_list[i].save(name)
    #Now we've sucessfully updated the unlabeled data
        
#Here we define a function for the RPI4 to capture a image with the OV5647
def capture_image(path,imstate):
    
    #First setting our directory to path
    os.chdir(path)
    
    #Creating a picamera object and initializing it
    picam2 = Picamera2()
    preview_config = picam2.create_preview_configuration(main={"size": (1280, 720)})
    picam2.configure(preview_config)
    picam2.start()
    time.sleep(1)
    metadata = picam2.capture_file("im_lot"+str(imstate)+".jpg")
    park_lot_image = im.open("im_lot"+str(imstate)+".jpg")
    picam2.close()
    return park_lot_image
    
#Here we define a function that will check if a folder(path) exceeds maximum memory
def max_memory(max_bytes,path):
    
    #First we change directories to the path
    os.chdir(path)
    #Now we fetch the size of the folder connected to the path
    num_bytes = os.path.getsize(path)
    
    #Now we check if num_bytes exceeds max_bytes
    if(num_bytes >= max_bytes):
        return 1
    else:
        return 0
##############################################################################################################
#Now we import the ML Model and the functions we'll need to make predictions

#Here we load in the ML Model
file1 = open('ML_Model_V1.2.obj','rb')
ann1 = pickle.load(file1)

#Here we utitlize a built in previous function from Park_IM_Pro.py that is modified to convert the images into 1d rgb arrays
def im_array1d(im):
    #value_index  = 120*i+3*j+k
    im_array = numpy.zeros(3600)
    for i in range(30):
        for j in range(40):
            for k in range(3):
                #Writing a RGB value into the array
                im_array[120*i +3*j +k] = im[j-1,i-1,k-1]        
    return im_array



#Here we make a function that will take in a image and resize them to 30x40 images, then convert each image into a 3d rgb array
def process_images(image,mask):
    
    #Here we segement the image with the mask and resize each image to be (30x40) in size
    image_list = []
    for i in range(mask.shape[0]):
        image_list.append(image.crop(box = mask[i,:]))
        image_list[i] = image_list[i].resize(size = (30,40))
        #Here we save the images in the ML_Model_Segements
        os.chdir("Machine-Learning-Model-Application/Data")
        image_list[i].save("image" + str(i) + ".jpg")
    
    #Now we take each image and convert it into a 3d numpy array
    image_rgb_list = []
    for i in range(len(image_list)):
         image_rgb_list.append(cv2.imread(image_list[i]))
         #Now we delete the images in the ML_Model_Segments folder
         os.chdir("Machine-Learning-Model-Application/Data")
         os.remove("image" + str(i) + ".jpg")
         
    #Now we take each 3d array and convert into a 1d array [r1,g1,b1,r2,g2 ... b1200] for each image
    image_rgb1d_list = []
    for i in range(len(image_list)):
        image_rgb1d_list.append(im_array1d(image_rgb_list[i]))
        
    #Now we store this list of 1d arrays in a pandas dataframe, each 1d list corresponds to an image
    image_df = pandas.DataFrame(image_rgb1d_list)
    return image_df


#Here we make a function that will take in the pandas dataframe and utilize the ML Model to produce a spot_array
def predict_spotarray(dataframe,model):
    
    #Here we a list for the spot array
    spot_array = []
    #Now we go through each row in pandas dataframe and make a prediction
    for i in range(dataframe.shape[0]):
        spot_array.append(model.predict(dataframe.iloc[[i]]))
    #Now we return the spot array
    return spot_array


#Here we make a function that will take in a image and draw the mask according to the spotarray (green,red) = (unoccupied/occupied)
def draw_mask(image,spotarray,mask):
    
    #Here define a Draw object for the image to draw mask
    im2 = ImageDraw.Draw(image)
    
    #Now we go into a for loop to draw each rectangle on the mask for our image
    for i in range(mask.shape[0]):
        
        #Getting the ith rectangle for the mask
        rect = mask[i,:]
        
        #Now we determine if rectangle is red or green
        if(spotarray[i] == 0):
            im2.rectangle(rect,fill = None,outline = (0,255,0))
        else:
            im2.rectangle(rect,fill = None,outline = (255,0,0))
        
    #Now we return the image that now has the mask drawn upon it
    return image
            
        
        
    
##############################################################################################################
#Now we define a kivy app with a kivy widget
    
#Here we define a class which is a child of the kivy app class that will handle generating our GUI
class data_gatherer_app(App):
    #building app, by returning/generating root widget
    def build(self): 
        #making/returning root widget
        mm = main_menu()
        return mm
    
#Now we define a kivy widget to be our root widget
class main_menu(GridLayout):
    
    #Here is the constructore for the main menu widget
    def __init__(self,**kwargs):
        
        #calling super classes constructor, we make the float layout the size of the window
        super(main_menu,self).__init__(**kwargs,rows = 2,orientation = 'tb-lr',size = Window.size)
        
        #Theser are instance variables that hold the user parameters
        self.csv_path = ""
        self.data_path = ""
        self.image_path = ""
        self.num_spots = 0
        self.time = 1
        self.impath = ""
        #This variable will control if the app continues to capture data
        self.state = 1
        #Here we make a variable to alternate the path of the image taken
        self.imstate = 1
        #Here we add a ML Model as a parameter
        self.model = ann1
        
        #Now we add a image widget and gridlayout widget for level 1 in widget tree
        self.park_lot_image = Image(keep_ratio = False)
        self.add_widget(self.park_lot_image)
        gl1 = GridLayout(cols = 2,orientation = 'tb-lr')
        self.add_widget(gl1)
        
        #Now we add 2 grid layouts to gridlayot 1 to organize widgets in level2 of widget tree
        gl2 = GridLayout(rows = 4,orientation = 'tb-lr')
        gl1.add_widget(gl2)
        gl3 = GridLayout(cols = 2,orientation = 'tb-lr')
        gl1.add_widget(gl3)
        
        #Now we add 1 label and the 3 buttons for gl2 and 2 gridlayouts for gl3 on layer 3 of widget tree
        t_label = Label(text = "Digi-Park Data-GatherApp",font_size = 20)
        gl2.add_widget(t_label)
        start = Button(text = "start")
        gl2.add_widget(start)
        stop = Button(text = "stop")
        gl2.add_widget(stop)
        exit_ = Button(text = "exit")
        gl2.add_widget(exit_)
        
        gl4 = GridLayout(rows = 5,orientation = 'tb-lr')
        gl3.add_widget(gl4)
        gl5 = GridLayout(rows = 5, orientation = 'tb-lr')
        gl3.add_widget(gl5)
        
        
        #Now we add the labels for the text inputs and the text inputs themselves on level 4 of widget tree
        mask_label = Label(text = "mask_csv_file_path: ",font_size = 15)
        gl4.add_widget(mask_label)
        data_label = Label(text = "unlabeled_datafolder_path: ",font_size = 15)
        gl4.add_widget(data_label)
        image_label = Label(text = "parking_image_path: ",font_size = 15)
        gl4.add_widget(image_label)
        numspots_label = Label(text = "num_spots: ",font_size = 15)
        gl4.add_widget(numspots_label)
        time_label = Label(text = "sampling_time[s]: ",font_size = 15)
        gl4.add_widget(time_label)
        
        self.mask_text = TextInput(font_size = 10, text = "1")
        gl5.add_widget(self.mask_text)
        self.data_text = TextInput(font_size = 10,text = "1")
        gl5.add_widget(self.data_text)
        self.image_text = TextInput(font_size = 10,text = "1" )
        gl5.add_widget(self.image_text)
        self.numspots_text = TextInput(font_size = 10)
        gl5.add_widget(self.numspots_text)
        self.time_text = TextInput(font_size = 10)
        gl5.add_widget(self.time_text)
        
        #Here we make start_capture a event that will be called every (1/20s)
        event = Clock.schedule_interval(self.start_capture,2)
        
        
        #Now we bind functions to our 3 buttons
        exit_.bind(on_press = self.close_app)
        start.bind(on_press = self.start)
        stop.bind( on_press = self.stop_capture)
        
        
    #This is a basic function to close the app
    def close_app(self,obj):
        #Get the current running app(stop it) and close window
        App.get_running_app().stop()
        Window.close()
        
    #Here we define a function for updating the state variable with start button
    def start(self,obj):
        self.state = 0
        
        
            
    #Here we define a function that will capture/process/save images of the parking lot
    #This function will be a callback and will be called every (1/20)s to get more image data
    def start_capture(self,obj):
       
        #Here we add a conditional statment to check if user has started capture
        if(self.state == 0):
            #Fetching the text input contents
            self.csv_path = self.mask_text.text
            self.data_path = self.data_text.text
            self.image_path = self.image_text.text
            self.num_spots = int(self.numspots_text.text)
            self.time = int(self.time_text.text)
                
            #We fetch the mask from the csv file
            mask = fetch_mask(self.csv_path,self.num_spots)
            #Now we capture ans image and save it in ipath
            im1 = capture_image(self.image_path,self.imstate)
            #Now we segment the image into indiviudal spots
            im_list = segment_image(mask,im1,self.data_path)
            #Now we save the images into the unlabeled data folder
            save_images(self.data_path,im_list)
            #Now we check if the folder in data_path exceeds maximum storage 1GB
            state = max_memory(1000000,self.data_path)
            print(state)
            if(state != 0):
                #If state is not 0 we exceeded max memory closing app
                App.get_running_app().stop()
                Window.close()
            
            #Now we start utilizing the ML Model,first we process the image taken into a pandas dataframe of images
            dataframe = process_images(im1,mask)
            #Now we make predictions on each image in the dataframe to get the spot array
            spotarray = predict_spotarray(dataframe,self.model)
            #Now we draw the mask on the image according to the spotarray
            masked_image = draw_mask(im1,spotarray,mask)
            
            #Now we delete the current image in the image folder and put in our masked image
            os.chdir("/home/user1/Desktop/Data_Gatherer/Image_Data")
            if(self.imstate != 1):
                os.remove(str(self.image_path)+"/im_lot"+str(self.imstate-1)+".jpg")
            masked_image.save(str(self.image_path)+"/im_lot"+str(self.imstate)+".jpg")
            #Updating the image state for the next image we take and the image widget source image
            self.park_lot_image.source = (str(self.image_path)"+/im_lot"+str(self.imstate)+".jpg")
            self.imstate = self.imstate +1
            
                
            
        #If user wants to stop capture
        else:
            print("capturing stopped")
            
    #Here we define a function that will stop the capture/process/save function
    def stop_capture(self,obj):
        #Here we simply update the self.state to 1 to stop capturing
        print(self.state)
        self.state = 1
    
    
        
    
        

#Here is the main function of the program that will run in a infinite loop
if __name__ == "__main__":
    
    #Create a new park_app object and run it
    l_data = data_gatherer_app()
    #l_data.run()
    thread1 = threading.Thread(target = l_data.run())
    thread1.start()
    

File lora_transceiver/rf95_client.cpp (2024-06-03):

//The majority (all but one portion) of this code is taken from github
//Link https://github.com/hallard/RadioHead/tree/master/examples/raspi/rf95

#include <bcm2835.h>
#include <stdio.h>
#include <signal.h>
#include <unistd.h>

#include <iostream>
#include <fstream>
#include <string>
#include <vector>

using namespace std;

#include <RH_RF69.h>
#include <RH_RF95.h>

//Pin definitions
#define RF_CS_PIN  RPI_V2_GPIO_P1_24 //Defines the chip select for the transmitter to be on GPIO pin 24 on the raspberry pi
#define RF_IRQ_PIN RPI_V2_GPIO_P1_22 //Defines the interupt dependant pin for the transmitter to be on GPIO pin 24 on the raspberry pi
#define RF_RST_PIN RPI_V2_GPIO_P1_15 //Defines the reset pin for the transmitter to be on GPIO pin 24 on the raspberry pi

// Our RFM95 Configuration 
#define RF_FREQUENCY  915.00 //Defines transmission frequency to be defined as 915 (Mhz)
#define RF_GATEWAY_ID 1      //Defines the reciever ID that we are sending data too
#define RF_NODE_ID    10     //Defines the node ID of the transmitter that we are using

//Create an instance of a driver
//This can be used to operate several transmitter at a time on one device (raspi)
//RH_RF95 is a class defined in the RH_RF95.h header, we are defining rf95 as an object to be used for the functions
RH_RF95 rf95(RF_CS_PIN, RF_IRQ_PIN);

//Flag for Ctrl-C from the Linux terminal
volatile sig_atomic_t force_exit = false;

//Creates a function to be used in signal() that sets force_exit to be true
void sig_handler(int sig)
{
  printf("\n%s Break received, exiting!\n", __BASEFILE__);
  force_exit=true;
}

//Main Function
int main (int argc, const char* argv[] )
{

  //Creates long to be used for delay between messages
  static unsigned long last_millis;
  
  //Returns the pointer to sig_handler() when SIGINT is interrupted by the force_exit flag
  //This function is used to stop the program after Ctrl-C is used in the Linux terminal
  signal(SIGINT, sig_handler);

  //__BASE_FILE__ is a macro that expands to the name of the main input file, in the form of a C string constant.
  //This is the source file that was specified on the command line of the preprocessor or C compiler.
  printf( "%s\n", __BASEFILE__);

  //checks to see if the bcm2835 library has been successfully initialized (so that the GPIO pins and SPi can be used on the Raspi)
  //If not then stop the program and print that bcm2835 has failed (useful for debugging)
  if (!bcm2835_init()) 
  {
    fprintf( stderr, "%s bcm2835_init() Failed\n\n", __BASEFILE__ );
    return 1;
  }
  
  printf( "RF95 CS=GPIO%d", RF_CS_PIN);

#ifdef RF_IRQ_PIN
  printf( ", IRQ=GPIO%d", RF_IRQ_PIN );
  //Sets the IRQ pin as input and pull down
  pinMode(RF_IRQ_PIN, INPUT);
  bcm2835_gpio_set_pud(RF_IRQ_PIN, BCM2835_GPIO_PUD_DOWN);
#endif
  
#ifdef RF_RST_PIN
  printf( ", RST=GPIO%d", RF_RST_PIN );
  //Pulse a reset on module (writing low, delay, then high to the pin)
  pinMode(RF_RST_PIN, OUTPUT);
  digitalWrite(RF_RST_PIN, LOW );
  bcm2835_delay(150);
  digitalWrite(RF_RST_PIN, HIGH );
  bcm2835_delay(100);
#endif

  //Checks to see if the hardware successfully initialized
  //If not then stop the program and print that the RF95w module has failed (useful for debugging)
  if (!rf95.init()) 
  {
    fprintf( stderr, "\nRF95 module init failed, Please verify wiring/module\n" );
  } else 
  {
    printf( "\nRF95 module seen OK!\r\n");


#ifdef RF_IRQ_PIN
    // Since we may check IRQ line with bcm_2835 Rising edge detection
    // In case the radio already has a packet, the IRQ pin will stay high and will never go low (to never fire again) 
    // Except if we clear IRQ flags and discard one if any by checking
    rf95.available();
    /*  
    The actual use of the function checks to see if a new message is available from the Driver 
    Returns true if a new, complete, error-free uncollected message is available to be retreived by the recv() function
    */

    //Enables Rising edge detection for the specific pin
    bcm2835_gpio_ren(RF_IRQ_PIN);
#endif

    //This function sets the power output to 14dBm (Can range from 2dBm to 20dBm for our module)
    //The boolean is used to distinguish how the transmitter module sets the power output
    //Since this library was written for several modules
    rf95.setTxPower(14, false); 

    //This function sets the frequency of the module (returns true if the frequency is within range)
    //Our module has the potential to set the frequency from 137Mhz to 1020Mhz
    //This module was manufactured to work best at either 868Mhz or 915Mhz
    //Ours will be set at 868
    rf95.setFrequency( RF_FREQUENCY );

    
    //This function sets the address of our node (transmitter)
    //The node ID is used to test the address in incoming messages on the reciever side
    //Allows for multi nodes for one reciever (all nodes have unique IDs)
    rf95.setThisAddress(RF_NODE_ID);
    //Set HeaderFrom as the same Node ID to prevent address spoofing
    rf95.setHeaderFrom(RF_NODE_ID);
    //Sets HeaderTo as the ID of the reciever we want to send data too
    rf95.setHeaderTo(RF_GATEWAY_ID);
    /*^^^^ The above three functions will be used in conjunction with the reciever to recieve messages from specific nodes                     ^^^^*/  
    /*^^^^ There is a function (setPromiscuous();) used by the reciever to set the module to recieve messages from any node or specific nodes  ^^^^*/

    printf("RF95 node #%d init OK @ %3.2fMHz\n", RF_NODE_ID, RF_FREQUENCY );

    //Sets last_millis to millis()
    //millis() returns the # of milliseconds since this program used one of the bcm2835 functions
    //This will be used to add delay between messages
    last_millis = millis();

    //Begin the main body of transmission code
    while (!force_exit) 
    {

      //Send data every 5 seconds
      if ( millis() - last_millis > 5000 ) 
      {
        //Resets the timer
        last_millis = millis();
        
        //Creates a string to place the contents of the text file into
        string Read_Arr;
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
